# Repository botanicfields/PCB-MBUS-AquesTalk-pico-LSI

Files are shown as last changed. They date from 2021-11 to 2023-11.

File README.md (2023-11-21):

# PCB-MBUS-AquesTalk-pico-LSI
# M5Stack用 AquesTalk pico LSIモジュール基板
M-BUS Module of AquesTalk pico LSI for M5Stack

# 1. 概要
　市販の音声合成専用LSI「AquesTalk pico LSI」（別売）をM-BUSモジュールとしてM5Stackに取り付けるための半完成基板です。  
　AquesTalk pico LSIの詳細は、データシートを参照ください。  
[Data Sheet: 音声合成 LSI 「AquesTalk pico LSI」ATP3011](https://www.a-quest.com/archive/manual/atp3011_datasheet.pdf)  
[Data Sheet: 音声合成 LSI 「AquesTalk pico LSI」ATP3012](https://www.a-quest.com/archive/manual/atp3012_datasheet.pdf)

### 基板V04の変更点
　2022年10月末から基板V04を提供しています。詳細は、スピーカーの接続の項を参照ください。

- ハンダジャンパJP8, JP9を追加しました。
- ランドJ5を追加しました。

### 委託販売
（スイッチサイエンス扱い）[M5Stack用 AquesTalk pico LSI モジュール基板](https://www.switch-science.com/collections/marketplace/products/7624)

### 動作例
（YouTube）["AquesTalk pico LSI" speaks date and time](https://youtu.be/DpDmjqU7RUM)  
（YouTube）[M-Bus Module of AquesTalk pico LSI drives the built-in speaker of M5Stack](https://youtu.be/npRQEOJegkY)  
（YouTube）[M-Bus Module of AquesTalk pico LSI for M5Stack](https://youtu.be/YfKwWRxrInM)  
（YouTube）[M-Bus Module of AquesTalk pico LSI for M5Stack on Core2](https://youtu.be/zXvg78xzJ5E)

### 組み立て例
　組み立てにはハンダ付けが必要です。

左側: ATP3011を搭載、音声アナログ信号をGPIO35に入力するためJP5をショート  
右側: ATP3012を搭載、音声アナログ信号をGPIO35に入力するためJP6をショート  
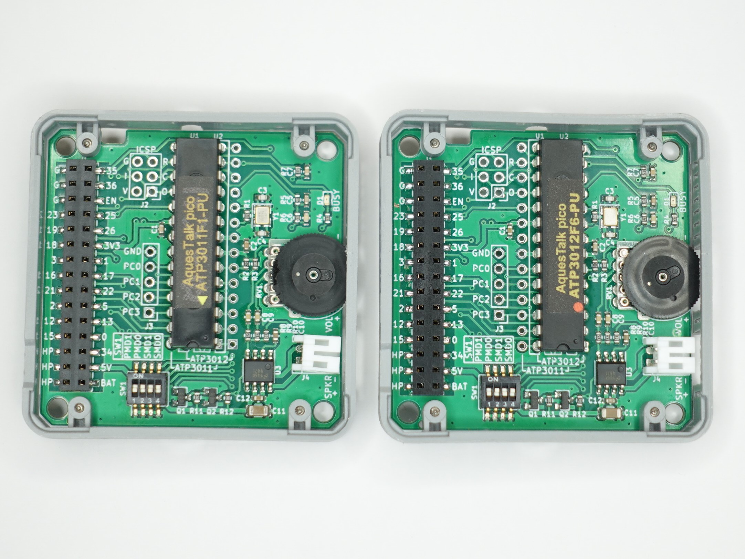
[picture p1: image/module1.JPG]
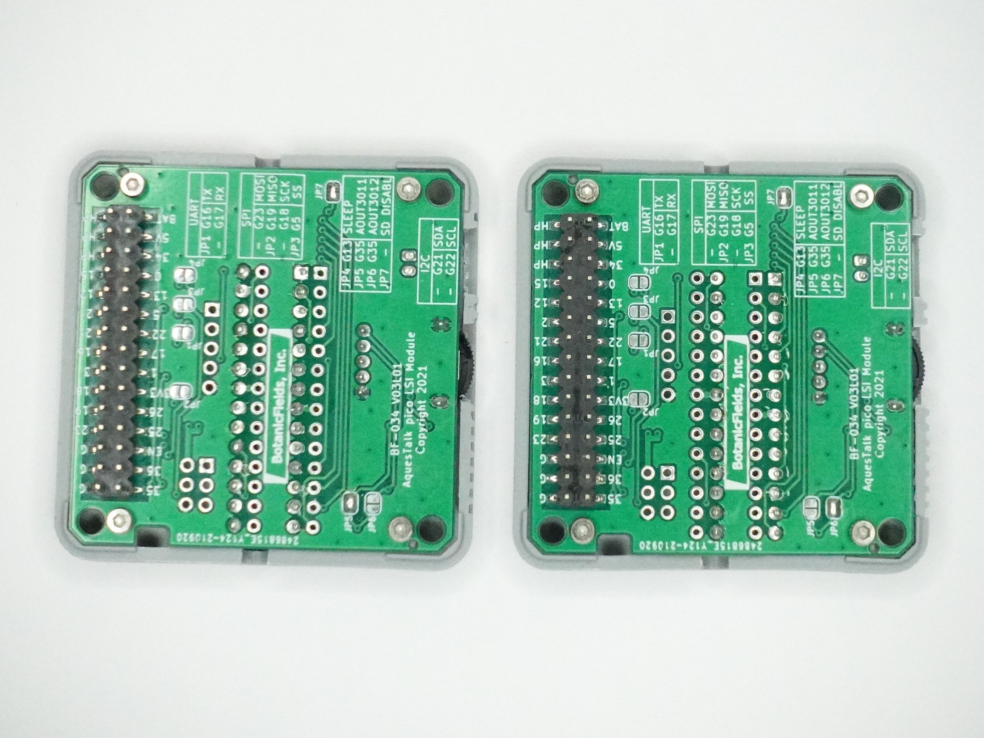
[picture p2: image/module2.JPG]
   
写真右: M5Stack 取り付け例、J4に外部スピーカを接続  
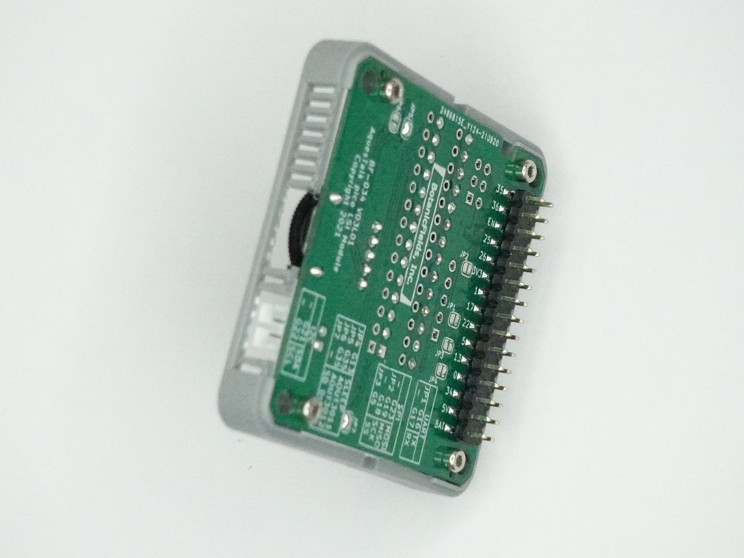
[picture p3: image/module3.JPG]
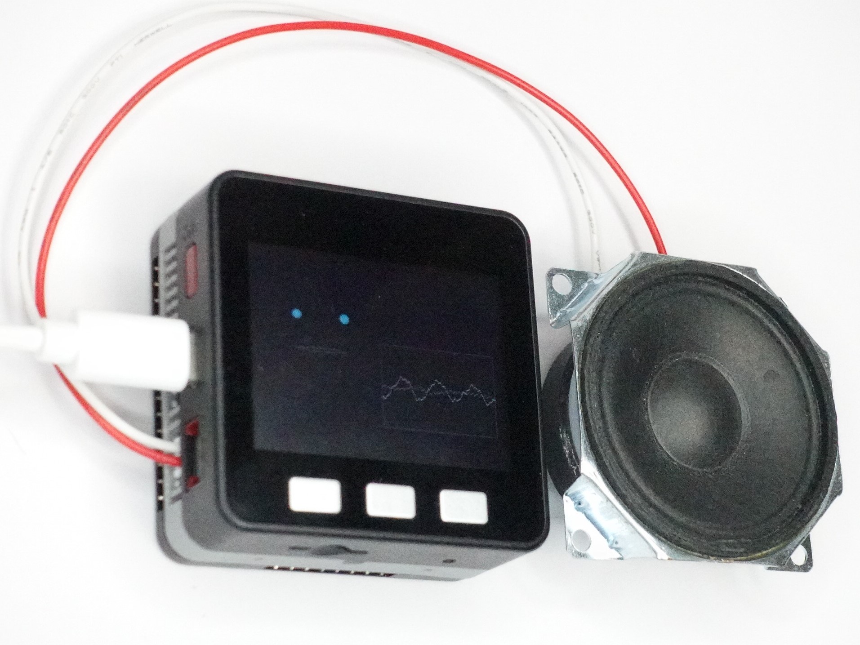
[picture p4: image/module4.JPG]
 

## 1.1 特徴
- AquesTalk pico LSI（28ピンDIPタイプ）1個を搭載できます。
- ATP3011, ATP3012の両方に対応しています。
- パワーアンプ（LM4871）を内蔵し、スピーカーを直接駆動できます。
- AquestTalk pico LSIを3.3Vで動作させ、M-BUSに直結できます。
- プロトモジュールのモールド（別売）を流用し、M5Stackに取り付けできます。
- スピーカー以外のケーブル接続が不要です。
- DIP スイッチで動作モード・通信モードを設定できます。
- インタフェースをI2C, UART, SPIから選べます。
- AquesTalk pico LSIの音声出力をM-BUSから取り込めます。
- M5StackのリセットでAquesTalk pico LSIをリセットします。
- スタンドアロンモードのためのランドがあります。

DIP: Dual In-line Package  
I2C: Inte-Integrated Circuit  
UART: Universal Asynchronous Receiver Transmitter  
SPI: Serial Peripheral Interface

## 1.2 商品内容
- M-BUS モジュール基板（半完成品）1枚  
- スピーカーケーブル 1組（2ピンPH相当コネクタ付き、20cm片端ストリップ済）  
（秋月電子通商扱い）[コネクタ付コード２Ｐ（Ａ）（赤白）DG01032-0045-01(C5679)](https://akizukidenshi.com/catalog/g/gC-05679/)
- 説明書 1部

※ AquesTalk pico LSIは付属しません。  
※ プロトモジュールのモールドは付属しません。  
※ スピーカーは付属しません。

### 商品写真
写真左: 内容物(基板V4)、写真右: 基板V4裏面  
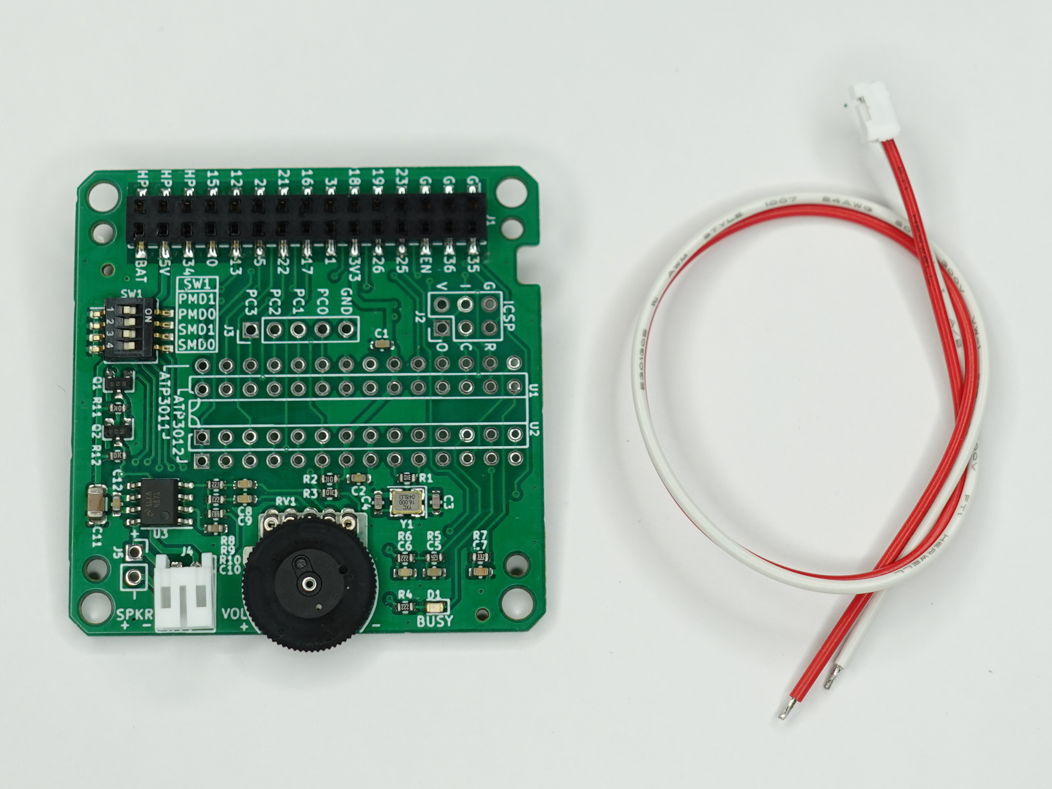
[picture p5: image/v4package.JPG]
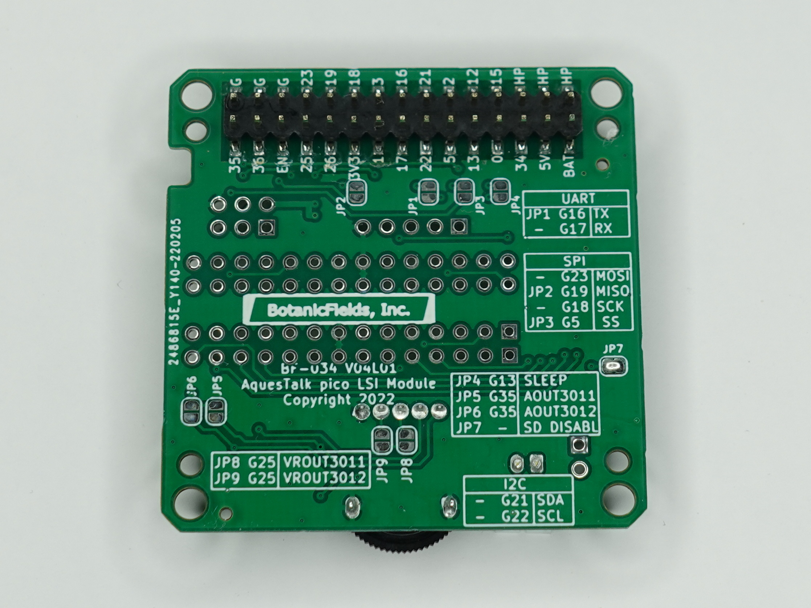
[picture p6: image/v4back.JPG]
 

## 1.3 別途必要なもの
- AquesTalk pico LSI（秋月電子通商扱い）  
[音声合成ＬＳＩ　ＡＴＰ３０１１Ｆ１－ＰＵ（ゆっくりな女性の音声）
ATP3011F1-PU](https://akizukidenshi.com/catalog/g/gI-06220/)  
[音声合成ＬＳＩ　ＡＴＰ３０１１Ｆ４－ＰＵ（かわいい女性の音声）
ATP3011F4-PU](https://akizukidenshi.com/catalog/g/gI-05665/)  
[音声合成ＬＳＩ　ＡＴＰ３０１１Ｍ６－ＰＵ（男性の音声）
ATP3011M6-PU](https://akizukidenshi.com/catalog/g/gI-06225/)  
[音声合成ＬＳＩ　ＡＴＰ３０１２Ｆ６－ＰＵ（女性の音声明瞭版）
ATP3012F6-PU](https://akizukidenshi.com/catalog/g/gI-09973/)  
[音声合成ＬＳＩ　ＡＴＰ３０１２Ｒ５－ＰＵ（小型ロボットの音声）
ATP3012R5-PU](https://akizukidenshi.com/catalog/g/gI-11517/)
- プロトモジュール  
（スイッチサイエンス扱い）[M5Stack用プロトモジュール](https://www.switch-science.com/catalog/3650/)
- スピーカー  
4～8Ω程度、1W以上が望ましいです。
- 工具  
ハンダ、ハンダごて、ニッパー、六角レンチ(1.5mm)、カッター、ピンセットなど
- M5Stack  
サンプルプログラムは、主にM5Stack Core Basicで動作を確認しています。
- Arudino-IDEが動作する環境  

# 2. モジュール基板の組み立て

## 2.1 AquesTalk pico LSI の取り付け
　別売のAquestTalk pico LSI（28ピンDIPタイプ）1個を取り付けます。ATP3011とATP3012とでは挿入する穴が異なります。基板上のシルク印刷に従ってピンを挿入しハンダ付けします。モジュール基板裏面から飛び出しているピンを短く切ってください。

左: ATP3011, 右: ATP3012  
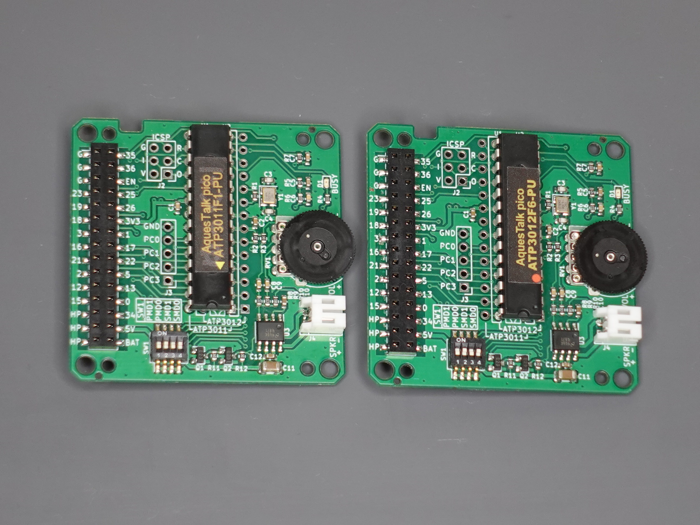
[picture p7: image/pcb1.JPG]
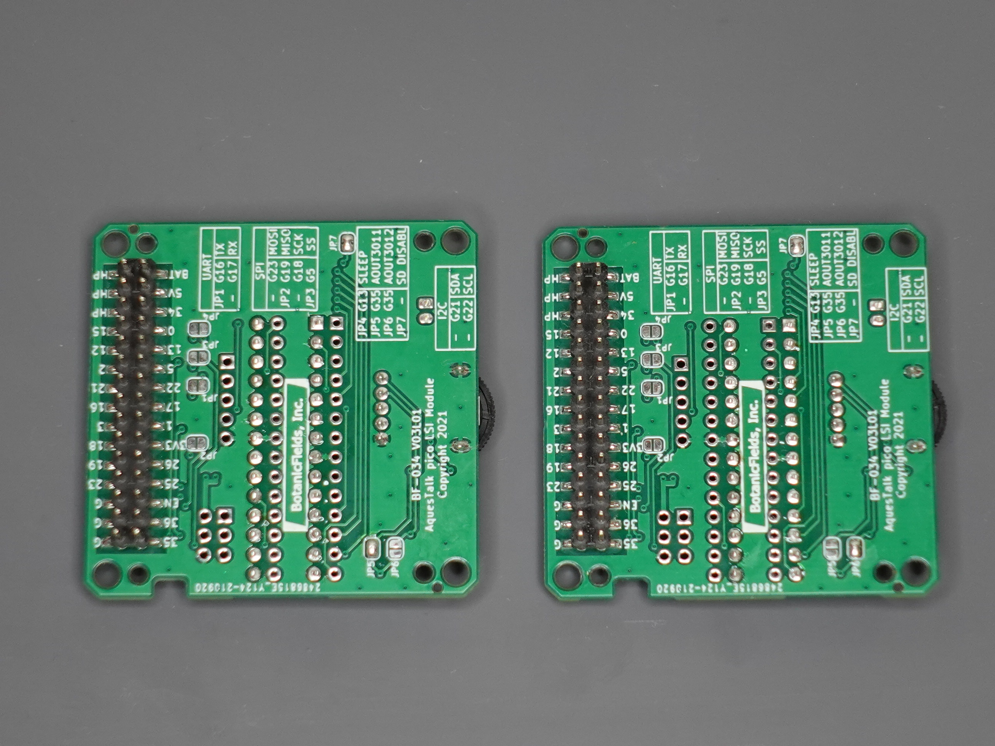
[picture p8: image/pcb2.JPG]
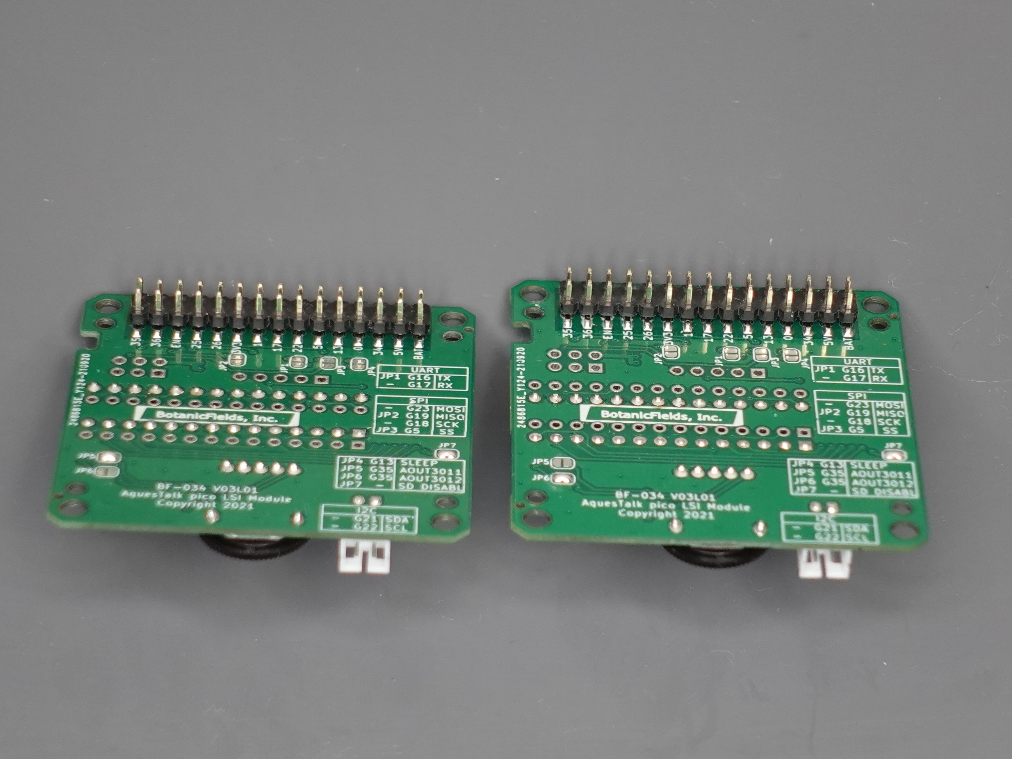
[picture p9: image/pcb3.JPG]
   

### ICソケットは使用できません
　ICソケットを使用すると、プロトモジュールのモールドには収まらなくなります。収まらなくなることを承知の上で1列タイプのICソケットを使用するとATP3011とATP3012を差し換えることができます。モジュール基板裏面からのピンの飛び出しの対処も大変になります。

- ICソケット（秋月電子通商扱い）  
[丸ピンＩＣ用ソケット　（シングル１４Ｐ）　１×１４　
6604S-14](https://akizukidenshi.com/catalog/g/gP-03470/)  
[丸ピンＩＣ用ソケット　（シングル１４Ｐ）　１×１４　
JS-11791SFTD-14](https://akizukidenshi.com/catalog/g/gP-11451/)  ※在庫限り  

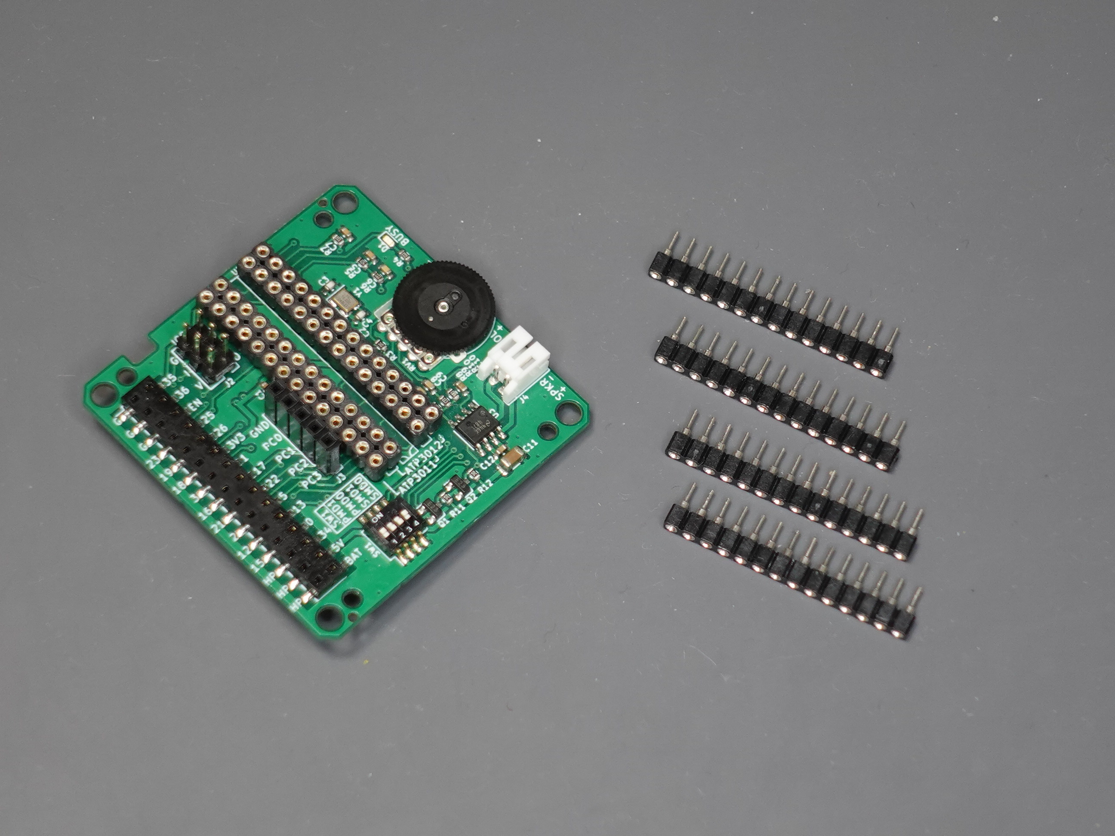
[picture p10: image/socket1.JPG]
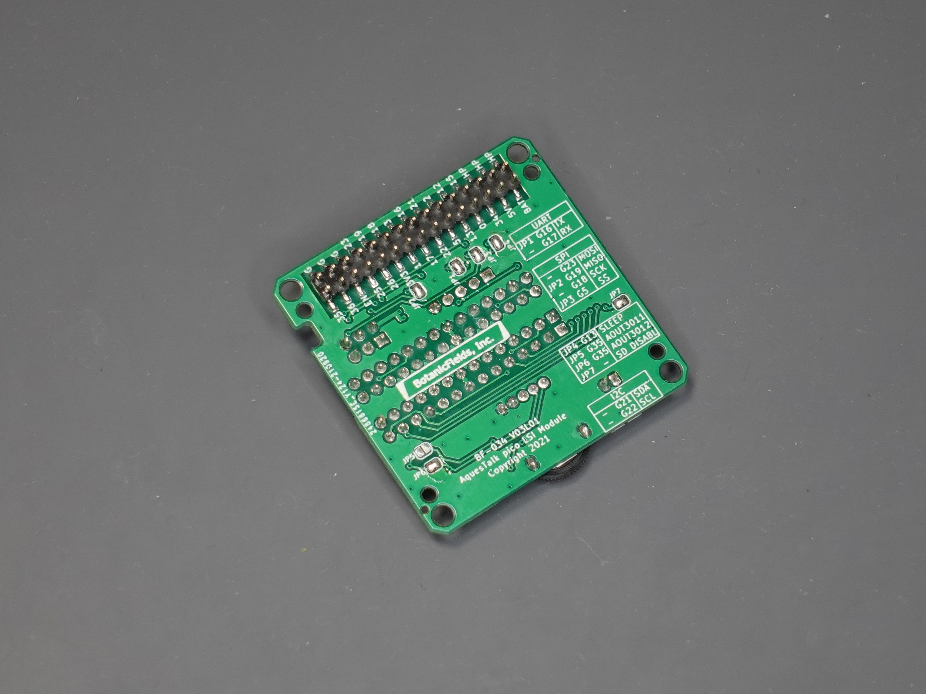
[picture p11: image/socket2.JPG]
 

## 2.2 モールドの取り付け
　プロトモジュールのモールドおよびネジ4本（別売）を流用して、M5StackのM-BUSモジュールに仕立てることができます。モールドを基板に取り付ける前に、ボリュームやスピーカー出力コネクタの部分をモールドから切り取ります。
### モールドの入手先（スイッチサイエンス扱い）

- [M5Stackプロトモジュール用プラスチックフレーム（2個入）](https://www.switch-science.com/collections/m5stack/products/8450)
- [M5Stack用プロトモジュール [M001]](https://www.switch-science.com/collections/m5stack/products/3650)

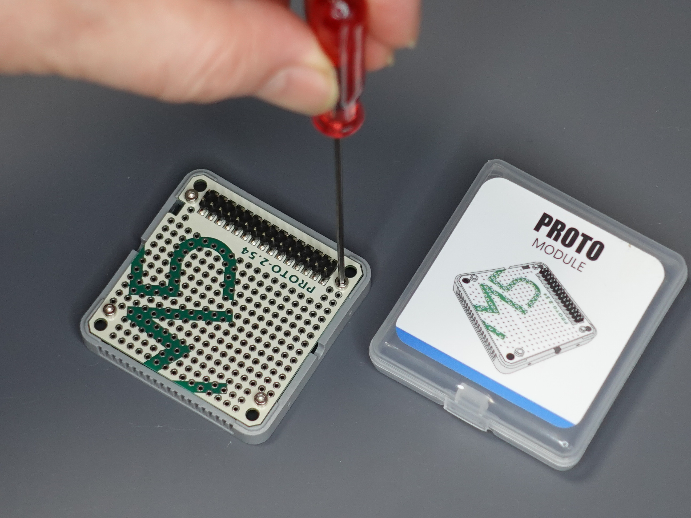
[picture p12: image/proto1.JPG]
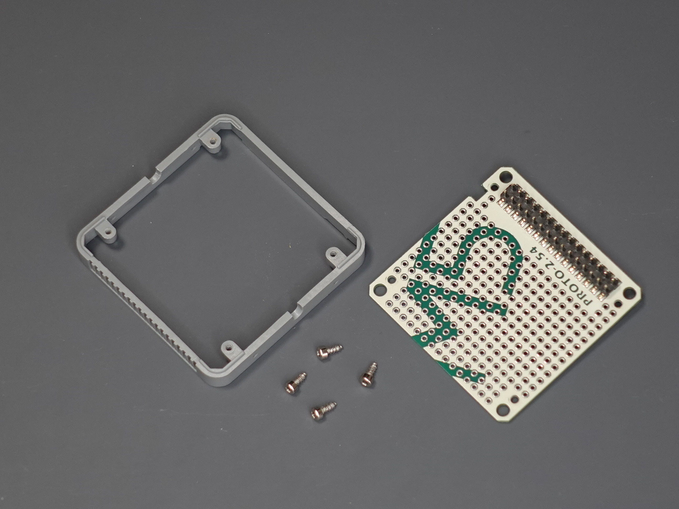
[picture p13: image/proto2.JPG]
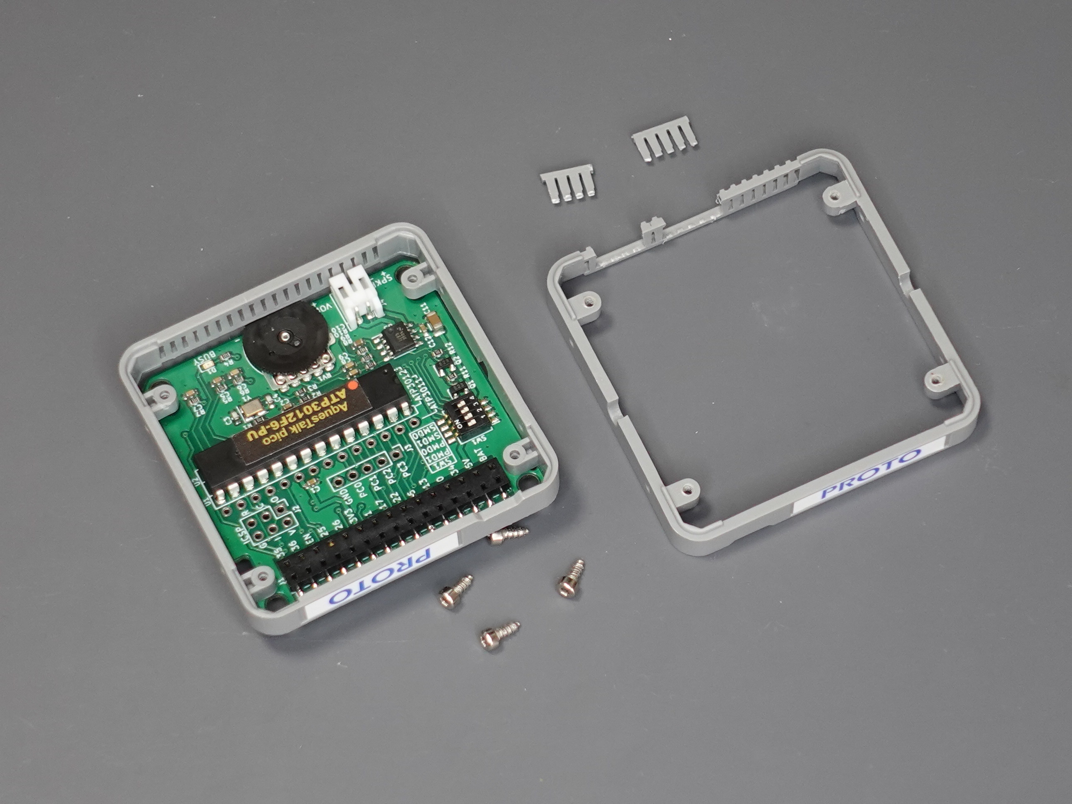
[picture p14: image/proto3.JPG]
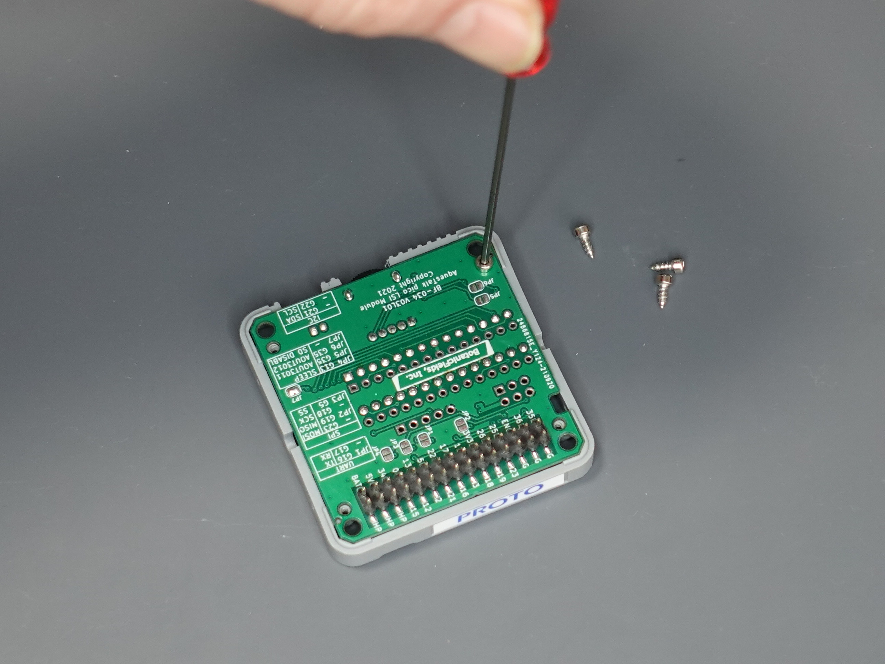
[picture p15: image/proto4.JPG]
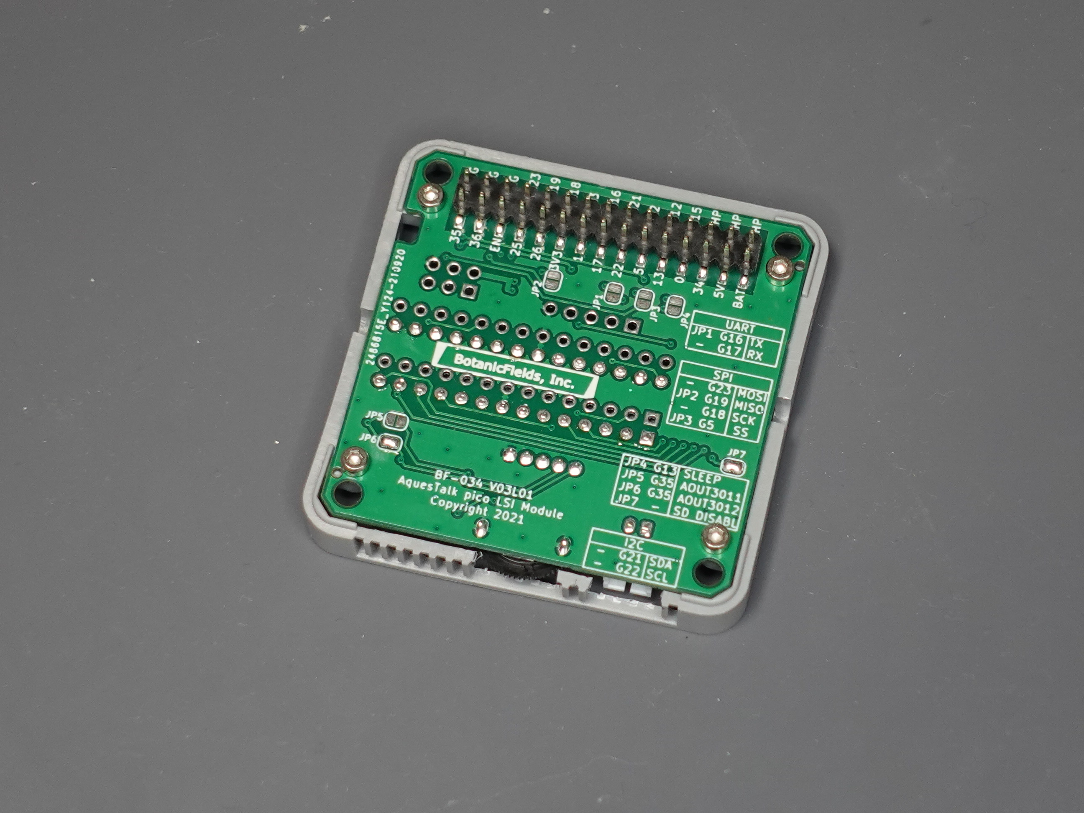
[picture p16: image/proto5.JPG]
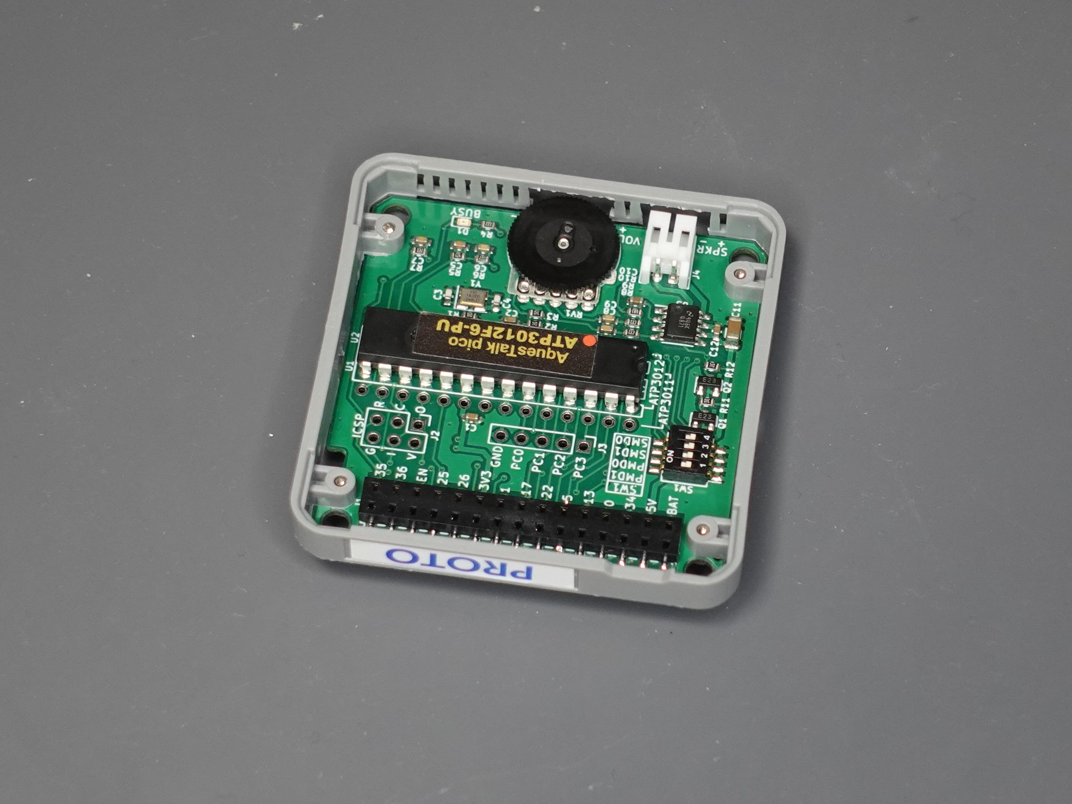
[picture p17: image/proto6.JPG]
     

## 2.3 スピーカーの接続

- 付属のケーブルでJ4とスピーカー（付属せず）を接続します。GNDには接続しないでください。
- （基板V4）J5にスピーカーを接続することができます。GNDには接続しないでください。
- （基板V4）M5Stack(Core1)の内蔵スピーカーを使用できます。ATP3011の場合はJP8を、ATP3012の場合はJP9をショートしてください。M5Stack本体からGPIO25を使用しないでください。Core2は内蔵スピーカーの回路構成が異なるため、この方法は使えません。  

左側: ATP3011を搭載、GPIO25, 35に接続するためJP8, JP5をショート(基板V4)  
右側: ATP3012を搭載、GPIO35に接続するためJP6をショート、J5にスピーカを接続(基板V4)  

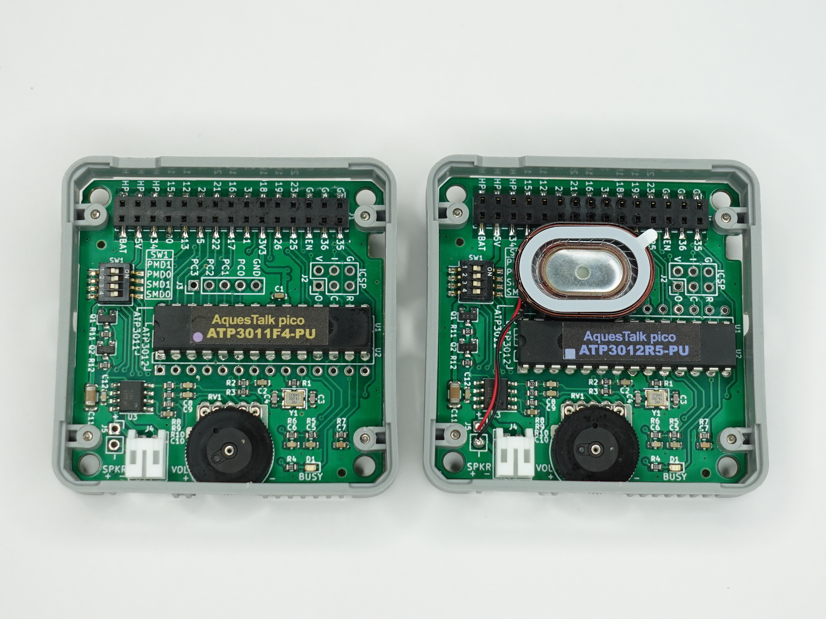
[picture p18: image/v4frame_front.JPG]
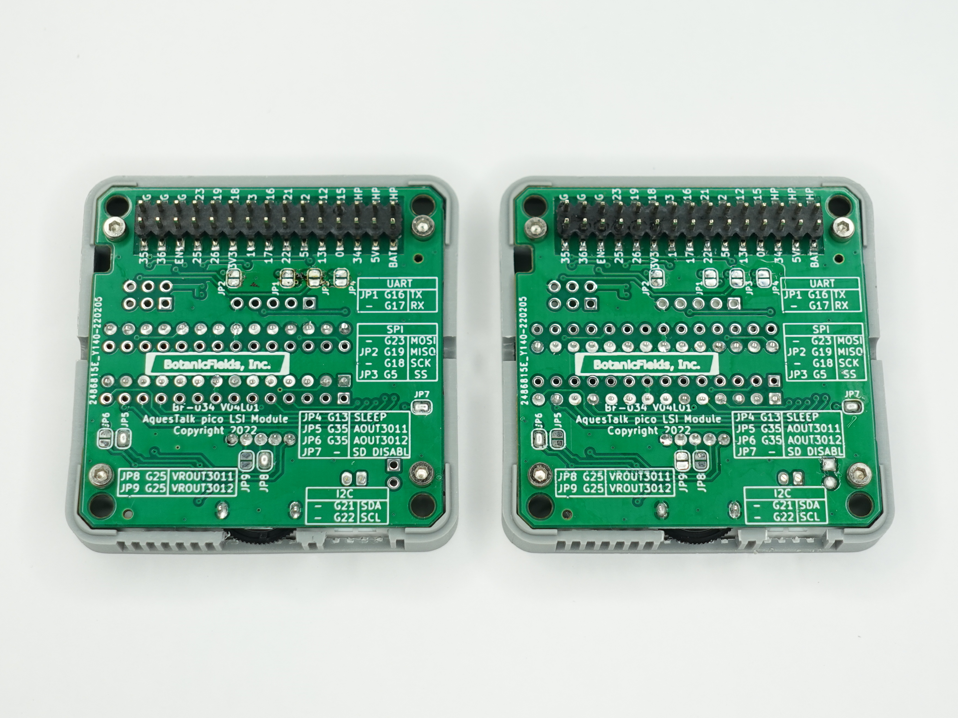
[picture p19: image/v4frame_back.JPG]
   

参考：写真のスピーカーは以下を両面テープで固定しています。ATP3012の場合かろうじて収まります。上に重ねるモジュールやボトムによっては収まりません。  
（秋月電子通商扱い）  
[マイクロスピーカー　赤／黒リード付　８Ω](https://akizukidenshi.com/catalog/g/gP-12494/)  
[マイクロスピーカー　青／白リード付　８Ω](https://akizukidenshi.com/catalog/g/gP-12495/)

### M5Stackの内蔵スピーカーについて
　M-BUSのGPIO25は、M5Stack内部のオーディオアンプを通して内蔵スピーカーに繋がっています。AquesTalk pico LSIからの音声出力をGPIO25に入力すれば、内蔵スピーカーから音声を出すことができます。ボリューム(VR)の出力を用いることで音量調節が可能です。以下の写真は、ATP3011を載せたモジュールにおいてGPIO25とボリューム出力を導線で接続した例です。ATP3012の場合は、ボリューム出力は1つ左側のピンです。基板V4のJP8, JP9はこれらの導線を埋め込んだものです。M5Stack自身がGPIO25を使わないことが前提です。Core2は内蔵スピーカーの回路構成が異なるため、この方法は使えません。

VR: Variable Resistor

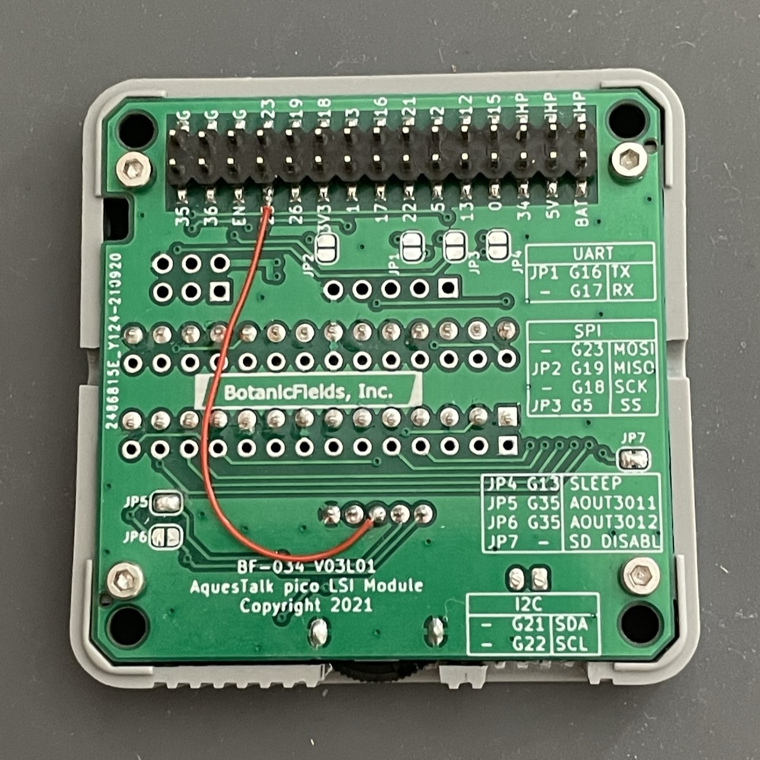
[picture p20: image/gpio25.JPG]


## 2.4 その他の端子
- J2は、ICSPです。コネクタ等は実装していません。使用にはピンヘッダをハンダ付けするなどの処置が必要です。ICSPのVCCはAquesTalk pico LSIの電源端子に繋がっているほか、M-BUSの3.3Vにも繋がっています。ICSPは、モジュール基板をM5Stackから切り離し、単体にして接続してください。  
ICSP: In Circuit Serial Programming  

- J3は、スタンドアロンモードで使用するPC0-3およびGNDの端子です。コネクタ等は実装していません。使用には信号ケーブルを直接ハンダ付けするなどの処置が必要です。

### スタンドアロン接続例
　M5Stack用 AquesTalk pico LSIモジュールをM-Busエクステンションに載せ、ダイオードマトリクススイッチ16基板を接続しています。M5Stackの電源とリセットを使用しています。  
（スイッチサイエンス扱い）[M-Busエクステンション基板キット](https://www.switch-science.com/catalog/7371/)  
（スイッチサイエンス扱い）[ダイオードマトリクススイッチ16基板](https://www.switch-science.com/catalog/7626/)  
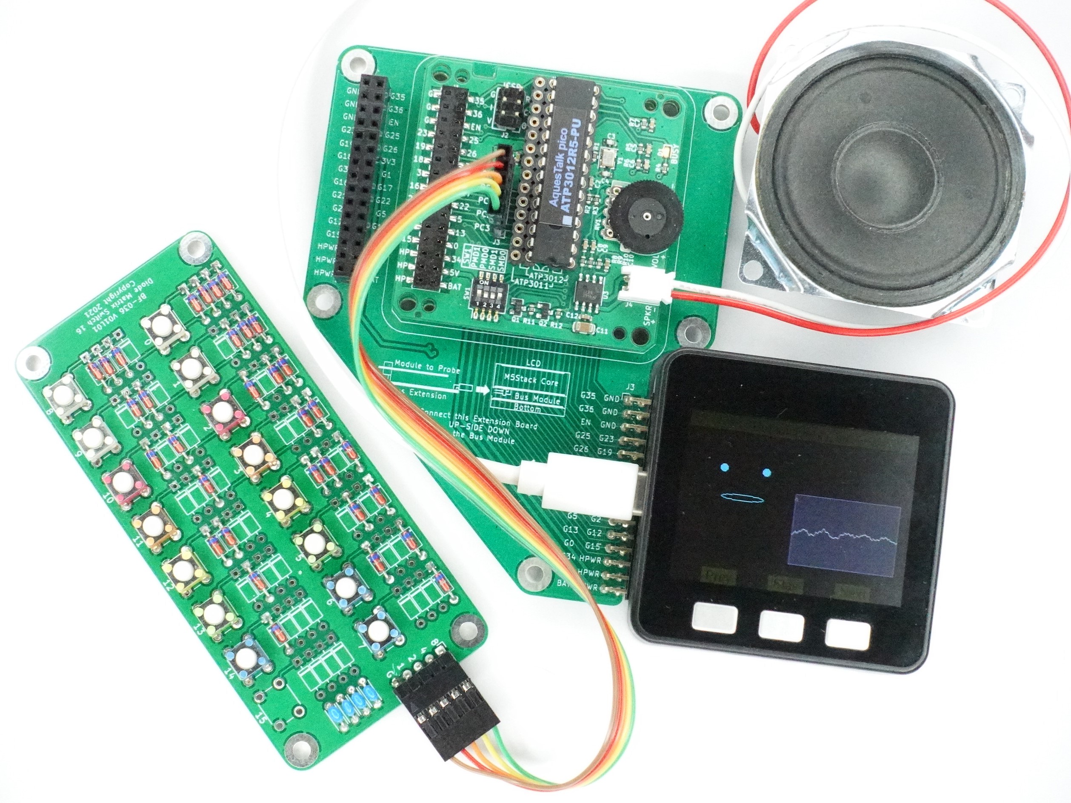
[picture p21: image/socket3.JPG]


# 3. モジュールの設定

## 3.1 DIPスイッチによる動作モード・通信モードの設定
　動作モードおよび使用するインタフェース（通信モード）に合わせて、モジュール基板上のDIPスイッチを設定します。設定にはピンセットなどが必要です。おすすめはI2C接続です。出荷時の設定は、セーフモード・I2C接続です。DIPスイッチの設定はリセット時に反映されます。AquesTalk pico LSIのリセットはM5Stackのリセットに繋がっています。

| 1 | 2 | 3 | 4 |動作モード|通信モード|備考|
|:-:|:-:|:-:|:-:|:-:|:-:|:- |
|OFF|OFF|OFF|ON | コマンド入力モード |I2C |I2CアドレスはEEPROMに設定した値（初期値0x2E）|
|OFF|ON |OFF|ON | セーフモード |I2C |I2Cアドレスは強制的に0x2E|
|OFF|OFF|OFF|OFF| コマンド入力モード |UART|設定されたスピードで動作 (*1) |
|OFF|ON |OFF|OFF| セーフモード |UART|強制的に9600bpsで動作|
|OFF| - |ON |OFF| - | SPI mode 3 | - |
|OFF| - |ON |ON | - | SPI mode 0 |サンプルプログラムはSPI mode 0で動作|
|ON |OFF| - | - | スタンドアロンモード | - |PC0-3の信号入力によりプリセットメッセージを選択して再生|
|ON |ON | - | - | デモモード | - |プリセットメッセージを順番に自動再生|

※ 1, 2, 3, 4は、DIPスイッチの番号。DIPスイッチはON=GNDのため、ON=0, OFF=1です。  
(*1) ATP3011の場合、SLEEP解除後の'?'送信で自動設定します。ATP3012の場合EEPROMに設定します。

## 3.2 ハンダジャンパによる信号の接続
　モジュール基板裏面のジャンパJP1-JP9をハンダで短絡（クローズ）することにより、GPIOとAquesTalk pico LSIの信号ピンを接続できます。

|ジャンパ|GPIO(Core1)|GPIO(Core2)|AquesTalk pico LSI|出荷時|
|:-:|:-:|:-:|:-|:-:|
|JP1|16|13|UART-TX|オープン|
|JP2|19|38|SPI-MISO|オープン|
|JP3|5|33|SPI-SS|オープン|
|JP4|13|19|SLEEP|オープン|
|JP5|35|35|Analog Out of ATP3011|オープン|
|JP6|35|35|Analog Out of ATP3012|オープン|
|JP7|GND|GND|Shut Down of Power Amplifier|クローズ|
|JP8|25|25|Analog VR Out of ATP3011|オープン|
|JP9|25|25|Analog VR Out of ATP3012|オープン|

### JP1, JP2, JP3: インタフェース信号
　使用するインタフェースに合わせてJP1, JP2, JP3をハンダで短絡（クローズ）します。I2Cの場合はJP1, JP2, JP3を全てオープンのままで使用できます。他の用途に影響がなければJP1, JP2, JP3を短絡（クローズ）することで全てのインタフェースを使用可能です。出荷時はオープンです。

|インタフェース|JP1|JP2|JP3|AquestTalk pico LSIピン=GPIO(Core1)|AquestTalk pico LSIピン=GPIO(Core1)|
|:-:|:-:|:-:|:-:|:- |:- |
|I2C| - | - | - |SDA=21, SCL=22|SDA=21, SCL=22|
|UART|クローズ| - | - |TX=16, RX=17|TX=13, RX=14|
|SPI| - |クローズ|クローズ|SCK=18, MISO=19, MOSI=23, SS = 5|SCK=18, MISO=38, MOSI=23, SS = 33|

SDA: Serial DAta  
SCL: Serial CLock  
RX: Receive  
TX: Transmit  
MISO: Master In Slave Out  
MOSI: Master Out Slave In  
SCK: Serial ClocK  
SS: Slave Select

### JP4: SLEEP 信号
　AquesTalk pico LSIのSLEEPピンをGPIO13(Core2ではGPIO19)に接続できます。SLEEP=LowでAquesTalk pico LSIがスリープ状態になります。ATP3011のUART接続において9600bpsより速い速度が必要な場合、「セーフモード」ではなく「コマンド入力モード」に設定し、速度設定のためにSLEEPを使用します。出荷時はオープンです。

### JP5, JP6: 音声信号の取り込み
　AquesTalk pico LSIの音声出力をGPIO35経由でM5Stackに取り込むことができます。ATP3011の場合はJP5を、ATP3012の場合はJP6をハンダで短絡（クローズ）します。出荷時はオープンです。

### JP7: パワーアンプのシャットダウン
　JP7がクローズ（短絡）の場合、パワーアンプのシャットダウン（SD: Shut Down）信号をGNDに接続しパワーアンプを常に動作状態とします。JP7のハンダを取り除く（オープン）にすると、AquesTalk pico LSIのPLAY信号（負極性）がシャットダウン信号となり、パワーアンプの消費電力を減らすことができます。この設定では音声再生の前後でノイズが発生します。出荷時はクローズ（短絡）です。

### JP8, JP9（基板V4）: M5Stack(Core1)の内蔵スピーカーへの接続
　AquesTalk pico LSIの音声出力をボリューム調節後にGPIO25経由でM5Stack内蔵アンプ・スピーカーに接続することができます。ATP3011の場合はJP8を、ATP3012の場合はJP9をハンダで短絡（クローズ）します。出荷時はオープンです。

# 4. サンプルプログラム
　AquesTalk pico LSIをM5Stackに接続し、I2C(Wire), UART(Serial), SPIで動作させるプログラムです。デモの内容は同じです。Arduino-IDE環境で使用します。モジュール基板の設定を予め使用するインタフェースに合わせておく必要があります。

### BF-034_Wireフォルダ
　AqeusTalk pico LSIをI2Cで動作させるサンプルプログラムです。

### BF-034_Serialフォルダ
　AqeusTalk pico LSIをUARTで動作させるサンプルプログラムです。

### BF-034_Spiフォルダ
　AqeusTalk pico LSIをSPIで動作させるサンプルプログラムです。

### BF-034_Core2_Wireフォルダ
　Core2にモジュールを装着して、AqeusTalk pico LSIをI2Cで動作させるサンプルプログラムです。M5Stack Core1との違いは以下です

- includeするヘッダーファイル
- WireのGPIOピン番号、SleepのGPIOピン番号

## 4.1 ボタン操作 .. loop()
　ボタンを押すと、ソースコードのpreset_msgを発声します。初期値はpreset_msg[0]です。

| M5 | ボタン | 停止中 | 発声中 |
|:-:|:-:|:-:|:-:|
|M5Stack| A | 1つ前のpreset_msgを発声 | 発声を中断して1つ前のpreset_msgを発声 |
|M5Stack| B | 現在のpreset_msgを発声 | 発声を中断して停止 |
|M5Stack| C | 1つ後のpreset_msgから連続して発声 | 発声を中断して1つ後のpreset_msgから連続して発生 |

## 4.2 setup()
- SLEEP ピンをHighにする（デフォルト: 実行する）  
　JP4をクローズ（短絡）すると、GPIO13(Core2ではGPIO19)とAquesTalk pico LSIのSLEEPピンとが接続します。SLEEPをHIGHにしてSLEEPでない状態にします。

- UARTスピードを設定（ATP3011が対象。UARTのみ。デフォルト: 実行しない）  
　AquesTalk pico LSI (ATP3011) のUARTスピードを設定します。GPIO13(Core2ではGPIO19)がAquesTalk pico LSIのSLEEPピンと接続している必要があります。

- UARTスピードを書き換え（ATP3012が対象。UARTのみ。デフォルト: 実行しない）  
　AquesTalk pico LSI (ATP3012) のUARTスピードを書き換えます。

- I2Cアドレスを書き換え（I2Cのみ。デフォルト: 実行しない）  
　AquesTalk pico LSIのI2Cアドレスを書き換えます。

- プリセットメッセージを書き込む（デフォルト: 実行しない）  
　AquesTalk pico LSIにプリセットメッセージとして、ソースコード内のpreset_msgデータを書き込みます。時間がかかります。

- EEPROMデータをダンプ（デフォルト: 実行しない）  
　AquesTalk pico LSIのEEPROMデータをシリアルモニタに表示します。時間がかかります。

- AquesTalk pico LSIのバージョンをシリアルモニタに表示

- チャイムJを発声

- チャイムKを発声

# 5. ライブラリ
　AquesTalk pico LSIを使用するためのライブラリです。

## 5.1 BF_AquesTalkPico.h
　I2C, UART, SPI共通の基本クラスです。接続するインタフェースに依ってI2C(Wire), UART(Serial), SPIのいずれかの派生クラスを使用する必要があります。

### (1) virtual int Send(const char* msg) = 0
　AquesTalk pico LSIに文字列msgを送信します。送信の様子をシリアルモニタに出力します。純粋仮想関数として定義し、使用するインタフェースに合わせて派生クラスで実装します。

### (2) virtual size_t Recv(char* res, size_t res_size) = 0
　AquesTalk pico LSIから文字列を受信します。受信完了は、'>'または'*'で判断します。純粋仮想関数として定義し、使用するインタフェースに合わせて派生クラスで実装します。

### (3) virtual bool Busy() = 0
　発声中などAquesTalk pico LSIが処理中の場合trueを応答します。falseの場合発声が終了したと判断できます。純粋仮想関数として定義し、使用するインタフェースに合わせて派生クラスで実装します。I2C, SPIではおのずとポーリングができますが、UARTではSend()による明示的なポーリングが必要です。

### (4) int ShowRes(int res_length_to_show = 1)
　AquesTalk pico LSIからの応答をシリアルモニタに出力します。res_length_to_showに2を渡すと、応答が1文字以下の場合にシリアルモニタへの出力を抑止できます。I2C、SPIのポーリングによる応答が正常（'>', 1文字）の場合のシリアルモニタへの出力を省略できます。

### (5) int DumpEeprom()
　AquesTalk pico LSIのEEPROM (アドレス0x000-0x3FF) の値をシリアルモニタに出力します。

### (6) int WriteEeprom(int address, int data)
　AquesTalk pico LSIのEEPROMにデータを書き込みます。

### (7) int WritePresetMsg(const char* msg[], int num_of_msg)
　AquesTalk pico LSIのEEPROMにプリセットメッセージを書き込みます。書き込みの様子をシリアルモニタに出力します。

### (8)  int WriteSpeed(int speed)
　発話速度をEEPROMに設定します。50～300を設定できます。デフォルトは100です。

### (9)  int WritePause(int pause)
　文末ポーズの長さをEEPROMに設定します。256～65535を設定できます。65535を設定すると自動になります。デフォルトは65535です。

### (10) int WriteSerialSpeed(int serial_speed)
　AquesTalk pico LSI (ATP3012) のシリアル通信速度を書き換えます。デフォルトは9600です。

### (11) int WriteI2cAddress(int i2c_address)
　AquesTalk pico LSIのI2Cアドレスを書き換えます。デフォルトは0x2Eです。

## 5.2 BF_AquesTalkPicoWire.h
　AquesTalk pico LSIとI2Cでインタフェースする派生クラスです。

### int Begin(TwoWire &wire, int i2c_address = 0x2e);
　AquesTalk pico LSIを接続するI2CとI2Cアドレスを指定します。

## 5.3 BF_AquesTalkPicoSerial.h
　AquesTalk pico LSIとUARTでインタフェースする派生クラスです。

### int Begin(Stream &stream);
　AquesTalk pico LSIを接続するUARTを指定します。

## 5.4 BF_AquesTalkPicoSpi.h
　AquesTalk pico LSIとSPIでインタフェースする派生クラスです。

### int Begin(SPIClass &spi, int ss);
　AquesTalk pico LSIを接続するSPIとSSとして使用するGPIOを指定します。

# 6. BF-034_Clockフォルダ
　M5StackのLCDに日付・時刻を表示する置時計のデモです。

- リセット後はsetupの状況を表示します。setupが完了しボタンCを押すと時計表示になります。
- ボタンBで日付を音声で読み上げます。ボタンCで時刻を音声で読み上げます。

### ご注意
　WiFi動作中に発声すると電圧低下を検出してリブートすることがあります。

### 参考情報

- Qiita: [ESP32のWiFiおよびtzapu/WiFiManagerにおいて回復処理を試行錯誤した](https://qiita.com/BotanicFields/items/8a73101a8bfe51e57f67)
- Qiita: [ESP32 において NTP の時刻同期を捕まえて RTC を更新する](https://qiita.com/BotanicFields/items/f1e28af5a63e4ccf7023)
- Qiita: [M5Atom, M5Stack Core 用の I2C リアルタイムクロック基板を作って動かす](https://qiita.com/BotanicFields/items/dc35e12423be8f6e9b4e)

# 7. 参考
- Qiita: [AquesTalk pico LSI を M5Stack の I2C, UART, SPI で動かす](https://qiita.com/BotanicFields/items/fff644f408c291e5a5f0)

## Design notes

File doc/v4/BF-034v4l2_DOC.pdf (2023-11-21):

BF-034 V04L02

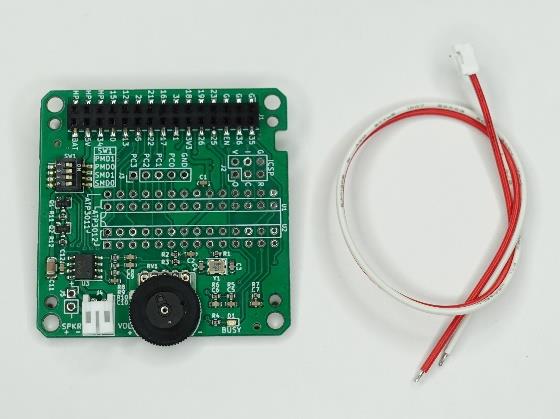
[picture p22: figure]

1 | Copyright 2022 BotanicFields, Inc.

## M5Stack 用 AquesTalk pico LSI モジュール基板

市販の音声合成専用 LSI「AquesTalk pico LSI」（別売）を M-BUS モ ジュールとして M5Stack に取り付けるための半完成基板です。 詳細は、以下を参照ください。
GitHub「PCB-MBUS-AquesTalk-pico-LSI」 https://github.com/botanicfields/PCB-MBUS-AquesTalk-pico-LSI Qiita「AquesTalk pico LSI を M5Stack の I2C, UART, SPI で動かす」 https://qiita.com/BotanicFields/items/fff644f408c291e5a5f0

AquesTalk pico LSI の詳細は、データシートを参照ください。 ATP3011: https://www.a-quest.com/archive/manual/atp3011_datasheet.pdf ATP3012: https://www.a-quest.com/archive/manual/atp3012_datasheet.pdf

1. 特徴

① AquesTalk pico LSI（28 ピン DIP タイプ）1 個を搭載できます。
② ATP3011, ATP3012 の両方に対応しています。
③ パワーアンプ（LM4871）を内蔵し、スピーカーを直接駆動できます。
④ AquesTalk pico LSI を 3.3V で動作させ、M-BUS に直結できます。
⑤ プロトモジュール（別売）のモールドを流用し、M5Stack に取り付けできます。 ⑥ スピーカー以外のケーブル接続が不要です。
⑦ DIP スイッチで動作モード・通信モードを設定できます。
⑧ インタフェースを I2C, UART, SPI から選べます。
⑨ AquesTalk pico LSI の音声出力を M-BUS から取り込めます。 ⑩ M5Stack のリセットで AquesTalk pico LSI をリセットします。 ⑪ スタンドアロンモードのためのランドがあります。
2. 商品内容

① M-BUS モジュール基板（半完成品）1 枚 (V04)
② スピーカーケーブル 1 組（2 ピン PH 相当コネクタ付き、20cm 片端ストリップ済） ③ 説明書（本書）

※基板 V04L01 と V04L02 は、製作上の都合による区別であり、機能・レイアウト共に全く同じです。

3. 別途必要なもの

① AquesTalk pico LSI（秋月電子通商扱い）音声合成ＬＳＩ ＡＴＰ３０１１Ｆ１－ＰＵ（ゆっくりな女性の音声）https://akizukidenshi.com/catalog/g/gI-06220/ＡＴＰ３０１１Ｆ４－ＰＵ（かわいい女性の音声） https://akizukidenshi.com/catalog/g/gI-05665/
ＡＴＰ３０１１Ｍ６－ＰＵ（男性の音声） | https://akizukidenshi.com/catalog/g/gI-06225/
ＡＴＰ３０１２Ｆ６－ＰＵ（女性の音声明瞭版） | https://akizukidenshi.com/catalog/g/gI-09973/
ＡＴＰ３０１２Ｒ５－ＰＵ（小型ロボットの音声） https://akizukidenshi.com/catalog/g/gI-11517/ ② M5Stack 用プロトモジュール（スイッチチサイエンス扱い） https://www.switch-science.com/catalog/3650/
③ スピーカー: 4～8Ω 程度、1W 以上が望ましいです。
④ 工具類: ハンダ、ハンダごて、ニッパー、六角レンチ(1.5mm)、カッター、ピンセットなど ⑤ M5Stack: サンプルプログラムは、M5Stack Core Basic で動作確認しています。
⑥ Arduino-IDE が動作する環境
4. モジュール基板の組み立て

① AquesTalk pico LSI の取り付け
AquesTalk pico LSI（28 ピン DIP パッケージ）を 1 個搭載できます。ATP3011 と ATP3012 とでは 取り付け穴が異なります。基板上のシルク印刷に従ってピンを差し込み、ハンダ付けします。ハンダ付 け後、基板裏面から飛び出しているピンを短く切ってください。IC ソケットは使用できません。プロト モジュールのモールドに収まらなくなります。

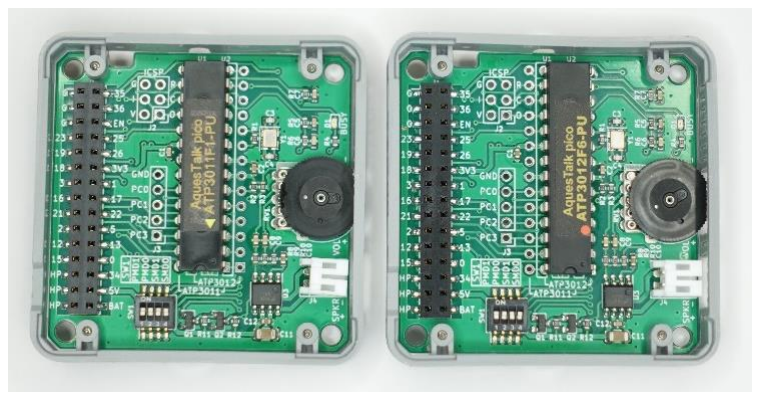
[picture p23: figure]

② モールドの取り付け
プロトモジュール（別売）のモールドおよびネジ 4
本を流用して、M5Stack の M-BUS モジュールに仕立 てることができます。モールドを基板に取り付ける前
に、ボリュームやスピーカー出力コネクタの部分をモ
ールドから切り取ります。

③ スピーカーの接続：以下から選択ください。
(1) 付属のケーブルで J4 とスピーカー（付属せず）を接続します。GND には接続しないでください。
(2) J5 にスピーカーを接続することができます。GND には接続しないでください。
(3) M5Stack(Core1)の内蔵スピーカーを使用できます。ATP3011 の場合は JP8 を、ATP3012 の場 合は JP9 をショートしてください。M5Stack 本体から GPIO25 を使用しないでください。Core2 は内蔵スピーカーの回路構成が異なるため、この方法は使えません。

左: ATP3011 右:ATP3012

5. モジュールの設定

① DIP スイッチ
動作モードおよび使用するインタフェース（通信モード）に合わせて、モジュール基板上の DIP スイ ッチを設定します。設定にはピンセットなどが必要です。おすすめは I2C 接続です。出荷時の設定は、 セーフモード、I2C 接続です。

(*1) ATP3011 の場合 SLEEP 解除後の'?'送信で自動設定。ATP3012 の場合 EEPROM に設定

② ハンダジャンパ
モジュール基板裏面のジャンパ JP1-JP9 をハンダで短絡（クローズ）することにより、GPIO と AquesTalk pico LSI の信号ピンを接続できます。
(1) JP1, JP2, JP3
使用するインタフェースに合わせて JP1, JP2, JP3 をハンダで短絡（クローズ）します。I2C の場合 は JP1, JP2, JP3 を全てオープンのままで使用できます。他の用途に影響がなければ JP1, JP2, JP3 を 短絡（クローズ）することで全てのインタフェースを使用可能です。

DIP スイッチ

1 | 2 | 3 | 4 | 動作モード | 通信モード | 備考
OFF | OFF | OFF | ON | コマンド入力モード | I2C | I2C アドレスは EEPROM に設定した値 （初期値 0x2E）
OFF | ON | OFF | ON | セーフモード | I2C | I2C アドレスは強制的に 0x2E
OFF | OFF | OFF | OFF | コマンド入力モード | UART | 設定されたスピードで動作 (*1)
OFF | ON | OFF | OFF | セーフモード | UART | 強制的に 9600bps で動作
OFF | - | ON | OFF | - | SPI mode 3 | -
OFF | - | ON | ON | - | SPI mode 0 | サンプルプログラムは SPI mode 0 で動作
ON | OFF | - | - | スタンドアロンモード | - | PC0-3 の信号入力によりプリセットメッ セージを選択して再生
ON | ON | - | - | デモモード | - | プリセットメッセージを順番に自動再生
ジャンパ | GPIO(Core1) | GPIO(Core2) | AquesTalk pico LSI | 出荷時設定
JP1 | 16 | 13 | UART-TX | オープン
JP2 | 19 | 38 | SPI-MISO | オープン
JP3 | 5 | 33 | SPI-SS | オープン
JP4 | 13 | 19 | SLEEP | オープン
JP5 | 35 | 35 | Analog Out of ATP3011 | オープン
JP6 | 35 | 35 | Analog Out of ATP3012 | オープン
JP7 | GND | GND | Shut Down of Power Amplifier | クローズ
JP8 | 25 | 25 | Analog VR Out of ATP3011 | オープン
JP9 | 25 | 25 | Analog VR Out of ATP3012 | オープン

(2) JP4
AquesTalk pico LSI の SLEEP ピンを GPIO13(Core2 では GPIO19)に接続できます。SLEEP = Low で AquesTalk pico LSI がスリープ状態になります。ATP3011 の UART 接続において 9600bps より 速い速度が必要な場合、「セーフモード」ではなく「コマンド入力モード」とし、速度設定のために SLEEP を使用します。
(3) JP5, JP6
AquesTalk pico LSI の音声出力を GPIO35 から M5Stack に取り込むことができます。ATP3011 の 場合は JP5 を、ATP3012 の場合は JP6 をハンダで短絡（クローズ）します。
(4) JP7
パワーアンプのシャットダウン（SD: Shut Down）信号を GND に接続し、パワーアンプを常に動 作状態とします。JP7 のハンダを取り除く（オープン）と、AquesTalk pico LSI の PLAY 信号（負極 性）がシャットダウン信号となり、パワーアンプの消費電力を減らすことができます。この設定では 音声再生の前後でノイズが発生します。
(5) JP8, JP9
AquesTalk pico LSI の音声出力をボリューム調節後に GPIO25 経由で M5Stack 内蔵アンプ・スピ ーカーに接続することができます。ATP3011 の場合は JP8 を、ATP3012 の場合は JP9 をハンダで短 絡（クローズ）します。Core2 では内蔵スピーカーの構成が異なるため接続できません。
6. サンプルプログラム

以下からダウンロードしてください。
GitHub「PCB-MBUS-AquesTalk-pico-LSI」 https://github.com/botanicfields/PCB-MBUS-AquesTalk-pico-LSI

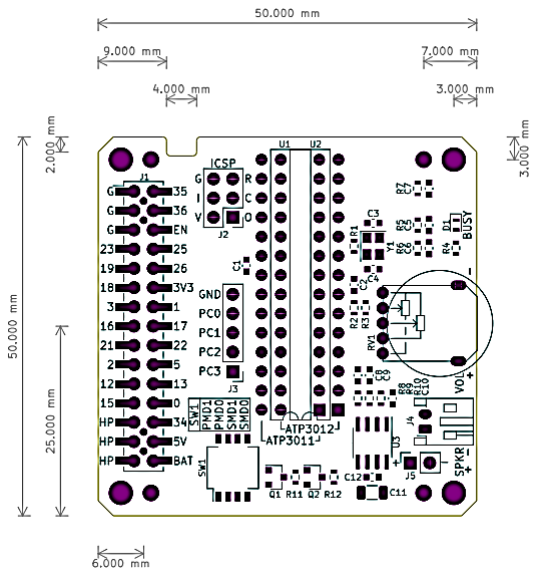
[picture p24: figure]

7. 基板裏面、表面

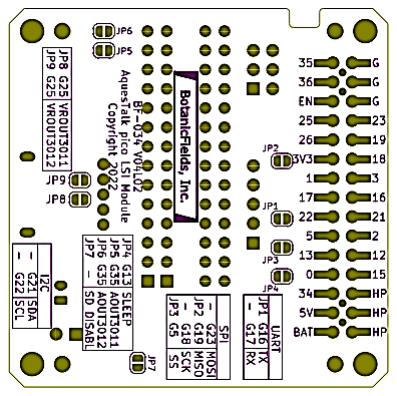
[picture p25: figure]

以上

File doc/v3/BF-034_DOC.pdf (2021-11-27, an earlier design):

BF-034 V03L01

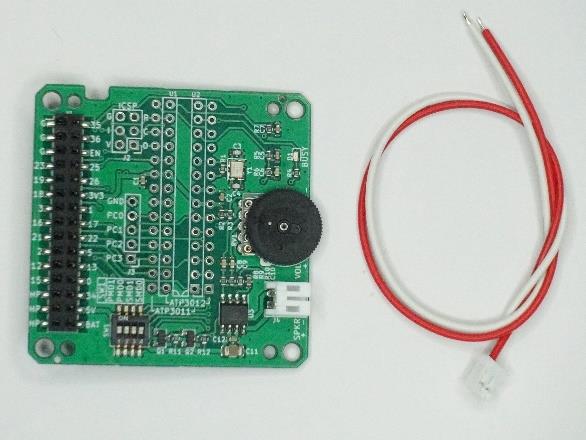
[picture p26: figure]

1 | Copyright 2021 BotanicFields, Inc.

## M5Stack 用 AquesTalk pico LSI モジュール基板

市販の音声合成専用 LSI「AquesTalk pico LSI」（別売）を M-BUS モ ジュールとして M5Stack に取り付けるための半完成基板です。 詳細は、以下を参照ください。
GitHub「PCB-MBUS-AquesTalk-pico-LSI」 https://github.com/botanicfields/PCB-MBUS-AquesTalk-pico-LSI Qiita「AquesTalk pico LSI を M5Stack の I2C, UART, SPI で動かす」 https://qiita.com/BotanicFields/items/fff644f408c291e5a5f0

AquesTalk pico LSI の詳細は、データシートを参照ください。 ATP3011: https://www.a-quest.com/archive/manual/atp3011_datasheet.pdf ATP3012: https://www.a-quest.com/archive/manual/atp3012_datasheet.pdf

1. 特徴
① AquesTalk pico LSI（28 ピン DIP タイプ）1 個を搭載できます。
② ATP3011, ATP3012 の両方に対応しています。
③ パワーアンプ（LM4871）を内蔵し、スピーカーを直接駆動できます。
④ AquestTalk pico LSI を 3.3V で動作させ、M-BUS に直結できます。
⑤ プロトモジュール（別売）のモールドを流用し、M5Stack に取り付けできます。 ⑥ スピーカー以外のケーブル接続が不要です。
⑦ DIP スイッチで動作モード・通信モードを設定できます。
⑧ インタフェースを I2C, UART, SPI から選べます。
⑨ AquesTalk pico LSI の音声出力を M-BUS から取り込めます。 ⑩ M5Stack のリセットで AquesTalk pico LSI をリセットします。 ⑪ スタンドアロンモードのためのランドがあります。
2. 商品内容
① M-BUS モジュール基板（半完成品）1 枚
② スピーカーケーブル 1 組（2 ピン PH 相当コネクタ付き、20cm 片端ストリップ済） ③ 説明書（本書）
3. 別途必要なもの
① AquesTalk pico LSI（秋月電子通商扱い）音声合成ＬＳＩ ＡＴＰ３０１１Ｆ１－ＰＵ（ゆっくりな女性の音声）https://akizukidenshi.com/catalog/g/gI-06220/ＡＴＰ３０１１Ｆ４－ＰＵ（かわいい女性の音声） https://akizukidenshi.com/catalog/g/gI-05665/
ＡＴＰ３０１１Ｍ６－ＰＵ（男性の音声） | https://akizukidenshi.com/catalog/g/gI-06225/
ＡＴＰ３０１２Ｆ６－ＰＵ（女性の音声明瞭版） | https://akizukidenshi.com/catalog/g/gI-09973/
ＡＴＰ３０１２Ｒ５－ＰＵ（小型ロボットの音声） https://akizukidenshi.com/catalog/g/gI-11517/ ② M5Stack 用プロトモジュール（スイッチチサイエンス扱い） https://www.switch-science.com/catalog/3650/

③ スピーカー: 4～8Ω 程度、1W 以上が望ましいです。
④ 工具類: ハンダ、ハンダごて、ニッパー、六角レンチ(0.5mm)、カッター、ピンセットなど ⑤ M5Stack: サンプルプログラムは、M5Stack Core Basic で動作確認しています。
⑥ Arudino-IDE が動作する環境
4. モジュール基板の組み立て
① AquesTalk pico LSI の取り付け
AquestTalk pico LSI（28 ピン DIP パッケージ）を 1 個搭載できます。ATP3011 と ATP3012 とでは 取り付け穴が異なります。基板上のシルク印刷に従ってピンを差し込み、ハンダ付けします。ハンダ付 け後、基板裏面から飛び出しているピンを短く切ってください。IC ソケットは使用できません。プロト モジュールのモールドに収まらなくなります。


② モールドの取り付け
プロトモジュール（別売）のモールドおよびネジ 4
本を流用して、M5Stack の M-BUS モジュールに仕立 てることができます。モールドを基板に取り付ける前
に、ボリュームやスピーカー出力コネクタの部分をモ
ールドから切り取ります。

③ スピーカーの接続
付属のケーブルで J4 とスピーカー（別売）を接続します。GND には接続しないでください。
5. モジュールの設定
① DIP スイッチ
動作モードおよび使用するインタフェース（通信モード）に合わせて、モジュール基板上の DIP スイ ッチを設定します。設定にはピンセットなどが必要です。おすすめは I2C 接続です。出荷時の設定は、 セーフモード、I2C 接続です。

(*1) ATP3011 の場合 SLEEP 解除後の'?'送信で自動設定。ATP3012 の場合 EEPROM に設定

DIP スイッチ

1 | 2 | 3 | 4 | 動作モード | 通信モード | 備考
OFF | OFF | OFF | ON | コマンド入力モード | I2C | I2C アドレスは EEPROM に設定した値 （初期値 0x2E）
OFF | ON | OFF | ON | セーフモード | I2C | I2C アドレスは強制的に 0x2E
OFF | OFF | OFF | OFF | コマンド入力モード | UART | 設定されたスピードで動作 (*1)
OFF | ON | OFF | OFF | セーフモード | UART | 強制的に 9600bps で動作
OFF | - | ON | OFF | - | SPI mode 3 | -
OFF | - | ON | ON | - | SPI mode 0 | サンプルプログラムは SPI mode 0 で動作
ON | OFF | - | - | スタンドアロンモード | - | PC0-3 の信号入力によりプリセットメッ セージを選択して再生
ON | ON | - | - | デモモード | - | プリセットメッセージを順番に自動再生

左: ATP3011 右:ATP3012

② ハンダジャンパ
モジュール基板裏面のジャンパ JP1-JP7 をハンダで短絡（クローズ）することにより、GPIO と AquesTalk pico LSI の信号ピンを接続できます。
(1) JP1, JP2, JP3
使用するインタフェースに合わせて JP1, JP2, JP3 をハンダで短絡（クローズ）します。I2C の場合 は JP1, JP2, JP3 を全てオープンのままで使用できます。他の用途に影響がなければ JP1, JP2, JP3 を 短絡（クローズ）することで全てのインタフェースを使用可能です。
(2) JP4
AquesTalk pico LSI の SLEEP ピンを GPIO13 に接続できます。GPIO13 = Low で AquesTalk pico LSI がスリープ状態になります。ATP3011 の UART 接続において 9600bps より速い速度が必要な場 合、「セーフモード」ではなく「コマンド入力モード」とし、速度設定のために SLEEP を使用します。
(3) JP5, JP6
AquesTalk pico LSI の音声出力を GPIO35 から M5Stack に取り込むことができます。ATP3011 の 場合は JP5 を、ATP3012 の場合は JP6 をハンダで短絡（クローズ）します。
(4) JP7
パワーアンプのシャットダウン（SD: Shut Down）信号を GND に接続し、パワーアンプを常に動 作状態とします。JP7 のハンダを取り除く（オープン）と、AquesTalk pico LSI の PLAY 信号（負極 性）がシャットダウン信号となり、パワーアンプの消費電力を減らすことができます。この設定では 音声再生の前後でノイズが発生します。
6. サンプルプログラム
以下からダウンロードしてください。
GitHub「PCB-MBUS-AquesTalk-pico-LSI」 https://github.com/botanicfields/PCB-MBUS-AquesTalk-pico-LSI
ジャンパ | GPIO | AquesTalk pico LSI | 出荷時設定
JP1 | 16 | UART-TX | オープン
JP2 | 19 | SPI-MISO | オープン
JP3 | 5 | SPI-SS | オープン
JP4 | 13 | SLEEP | オープン
JP5 | 35 | Analog Out of ATP3011 | オープン
JP6 | 35 | Analog Out of ATP3012 | オープン
JP7 | GND | Shut Down of Power Amplifier | クローズ

7. 基板表面、裏面

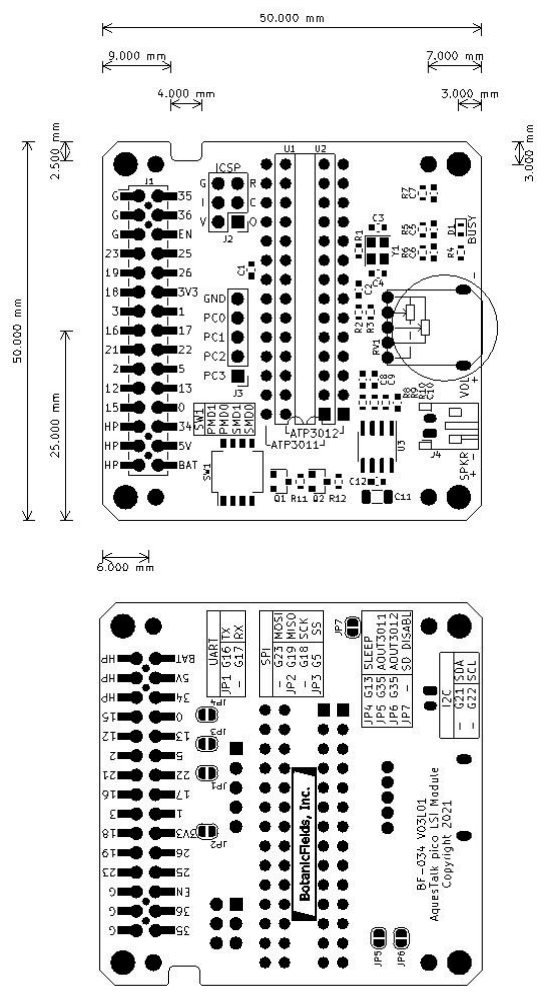
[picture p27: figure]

以上

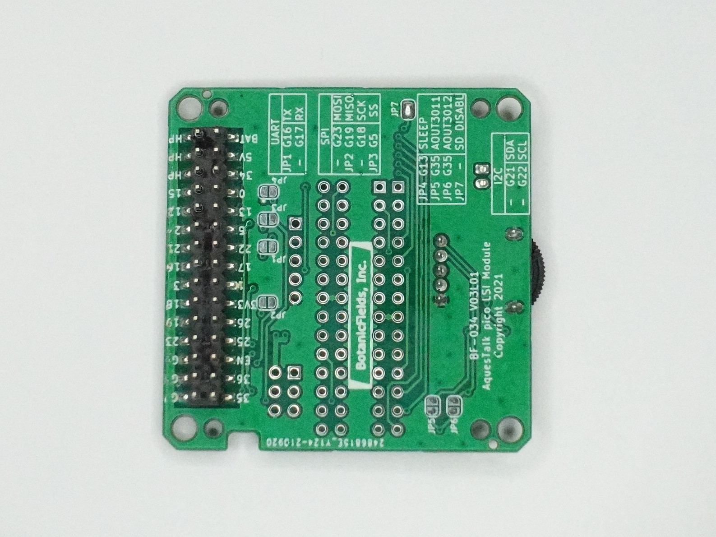
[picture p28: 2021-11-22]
image/product2.JPG

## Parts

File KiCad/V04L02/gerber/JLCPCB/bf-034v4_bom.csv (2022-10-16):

Comment | Designator | Footprint | LCSC
1u | C10 | bf:BF@C_0603_1608Metric | C15849
22u | C11 | Capacitor_SMD:C_1206_3216Metric | C5672
100n | C1,C2,C5,C12 | bf:BF@C_0603_1608Metric | C14663
10p | C3,C4 | bf:BF@C_0603_1608Metric | C1634
22n | C6 | bf:BF@C_0603_1608Metric | C21122
10n | C7 | bf:BF@C_0603_1608Metric | C57112
33n | C8,C9 | bf:BF@C_0603_1608Metric | C21117
BUSY | D1 | bf:BF@LED_0603_1608Metric | C72038
MountingHole | H1,H2,H3,H4 | bf:BF@MountingHole_3.2mm_M3
MountingHole | H5,H6,H7,H8 | bf:BF@MountingHole_2.2mm_M2
M-BUS | J1 | bf:BF@M5Stack_MBUS
ICSP | J2 | Connector_PinHeader_2.54mm:PinHeader_2x03_P2.54mm_Vertical
PRESET | J3 | Connector_PinHeader_2.54mm:PinHeader_1x05_P2.54mm_Vertical
SPKR | J4 | Connector_JST:JST_PH_S2B-PH-K_1x02_P2.00mm_Horizontal
SPKR | J5 | Connector_PinSocket_2.54mm:PinSocket_1x02_P2.54mm_Vertical
TXD | JP1 | Jumper:SolderJumper-2_P1.3mm_Open_RoundedPad1.0x1.5mm
MISO | JP2 | Jumper:SolderJumper-2_P1.3mm_Open_RoundedPad1.0x1.5mm
SS | JP3 | Jumper:SolderJumper-2_P1.3mm_Open_RoundedPad1.0x1.5mm
SLEEP | JP4 | Jumper:SolderJumper-2_P1.3mm_Open_RoundedPad1.0x1.5mm
AOUT3011 | JP5 | Jumper:SolderJumper-2_P1.3mm_Open_RoundedPad1.0x1.5mm
AOUT3012 | JP6 | Jumper:SolderJumper-2_P1.3mm_Open_RoundedPad1.0x1.5mm
SD_DISABLE | JP7 | Jumper:SolderJumper-2_P1.3mm_Open_RoundedPad1.0x1.5mm
VROUT3011 | JP8 | Jumper:SolderJumper-2_P1.3mm_Open_RoundedPad1.0x1.5mm
VROUT3012 | JP9 | Jumper:SolderJumper-2_P1.3mm_Open_RoundedPad1.0x1.5mm
DTC143Z | Q1,Q2 | Package_TO_SOT_SMD:SOT-23 | C15236
1M | R1 | bf:BF@R_0603_1608Metric | C22935
68k | R10 | bf:BF@R_0603_1608Metric | C23231
10k | R2,R3,R11,R12 | bf:BF@R_0603_1608Metric | C25804
2.2k | R4,R6 | bf:BF@R_0603_1608Metric | C4190
470 | R5 | bf:BF@R_0603_1608Metric | C23179
3.3k | R7 | bf:BF@R_0603_1608Metric | C22978
22k | R8,R9 | bf:BF@R_0603_1608Metric | C31850
10kA | RV1 | bf:BF@RK10J
MODE | SW1 | Button_Switch_SMD:SW_DIP_SPSTx04_Slide_KingTek_DSHP04TS_W7.62mm_P1.27mm | C319050
ATP3011 | U1 | Package_DIP:DIP-28_W7.62mm
ATP3012 | U2 | Package_DIP:DIP-28_W7.62mm
LM4871 | U3 | Package_SO:SOIC-8_3.9x4.9mm_P1.27mm | C7554
16MHz | Y1 | Crystal:Crystal_SMD_3225-4Pin_3.2x2.5mm | C13738

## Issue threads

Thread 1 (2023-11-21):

[Question][M5Stack Core2 IoT] UARTモード でのGPIOアドレスについて

nagayaoh, 2023-11-21:
## 概要: UARTモード でのGPIOアドレスについて
### Issueタイプ [Question]
### 問い合わせ内容
- ボード動作：　動作中
- ドキュメント内容と実際が異なる
  - ドキュメントではGPIOの割り当ては以下の記載
　　　  - rx: 16
　　　  - tx: 17
  - 環境でSerial2の割り当て(ソースコード)を追ってみると、
　　　  - rx: 13
　　　  - tx: 14
- コメント
  - 動作しているので、パッケージの差異あるいはドキュメント外の仕様かとも思いましたが、念の為確認です。
  - 何か懸念があればフィードバックください

### 環境情報
- Board Ver. : v4
- Pico LSI: ATP3012
- 開発環境: PlatformIO (Core 6.1.11·Home 3.4.4)
　　　- Board: M５Stack Core2
　　　- 確認Package: M5Core2
- ボード ジャンパ設定
　　　- JP1: Close UART-TX
　　　- JP2: Close SPI-MISO
　　　- JP3: Close SPI-SS
　　　- JP4: Close SLEEP ※ 3012だが誤ってCloseしたまま → **何か影響ありますか？**
　　　- JP6: Close Analog Out of ATP3012

## 確認した情報
#### Serial2 定義
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

#### logical pins
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

#### map logical pins to GPIO numbers
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

#### 【引用】 Readme.md ジャンパピン
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

uehara00, 2023-11-21:
ご指摘ありがとうございます。
当初M5Stack Core1で動作確認し、後日Core2用のサンプルプログラムを追加しましたが、ドキュメントの更新に漏れがありました。ドキュメントを更新いたします。販売中の商品への反映はもうしばらくかかります。

Core1のM-BUSピン配置
https://docs.m5stack.com/en/core/basic_v2.7
Core2のM-BUSピン配置
https://docs.m5stack.com/en/core/core2

uehara00, 2023-11-21:
シリアルインターフェースのボーレート設定において、ATP3012ではSLEEPは使用しませんが、ATP3012にもSLEEP機能があり本来のSLEEP動作をさせることができます。サンプルプログラムの範囲では特に影響はないと思います。
JP4をOpenにすると、GPIO19(Core1の場合はGPIO13)を他の用途に使える様になります。

ATP3012データシート
https://www.a-quest.com/archive/manual/atp3012_datasheet.pdf

uehara00, 2023-11-21:
README.mdとdoc/v4/BF-034v4l2_DOC.pdfを更新しました。

nagayaoh, 2023-11-21:
フィードバックありがとうございます。

確認いたしましたので、本件Closeいたします。

Closed 2023-11-21.

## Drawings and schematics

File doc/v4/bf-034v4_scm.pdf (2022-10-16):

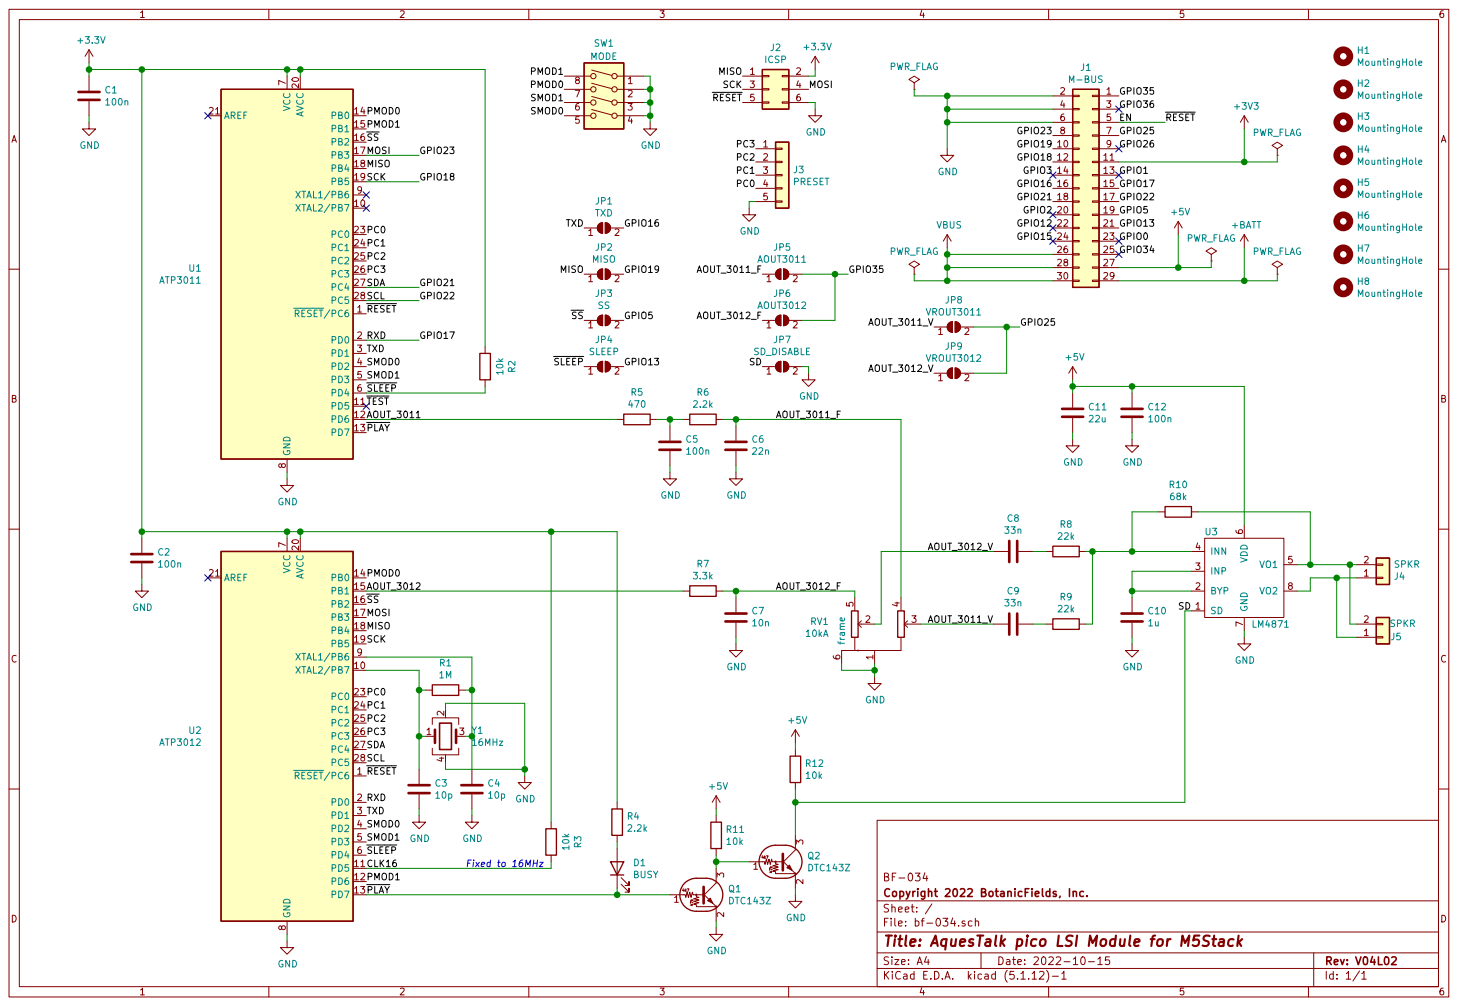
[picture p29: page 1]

File: bf-034.sch Sheet: / Copyright 2022 BotanicFields, Inc. BF-034 C3

Id: 1/1 Title: AquesTalk pico LSI Module for M5Stack

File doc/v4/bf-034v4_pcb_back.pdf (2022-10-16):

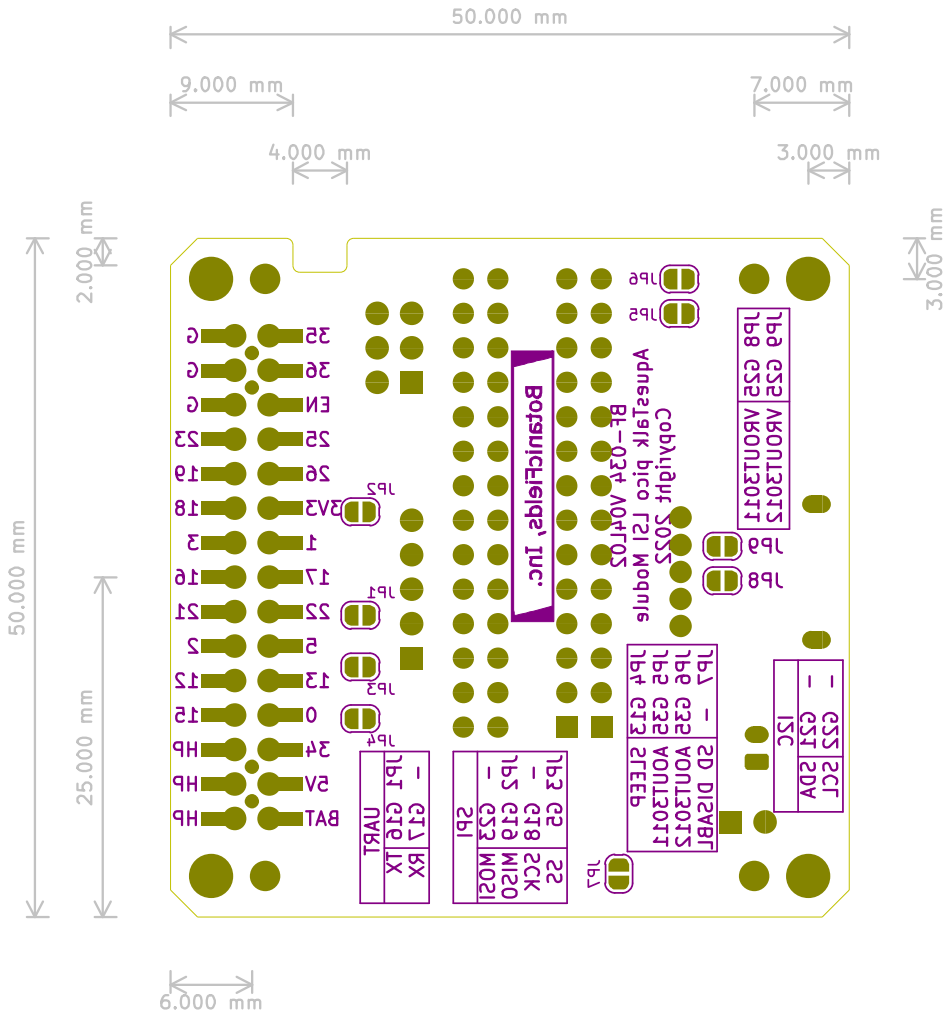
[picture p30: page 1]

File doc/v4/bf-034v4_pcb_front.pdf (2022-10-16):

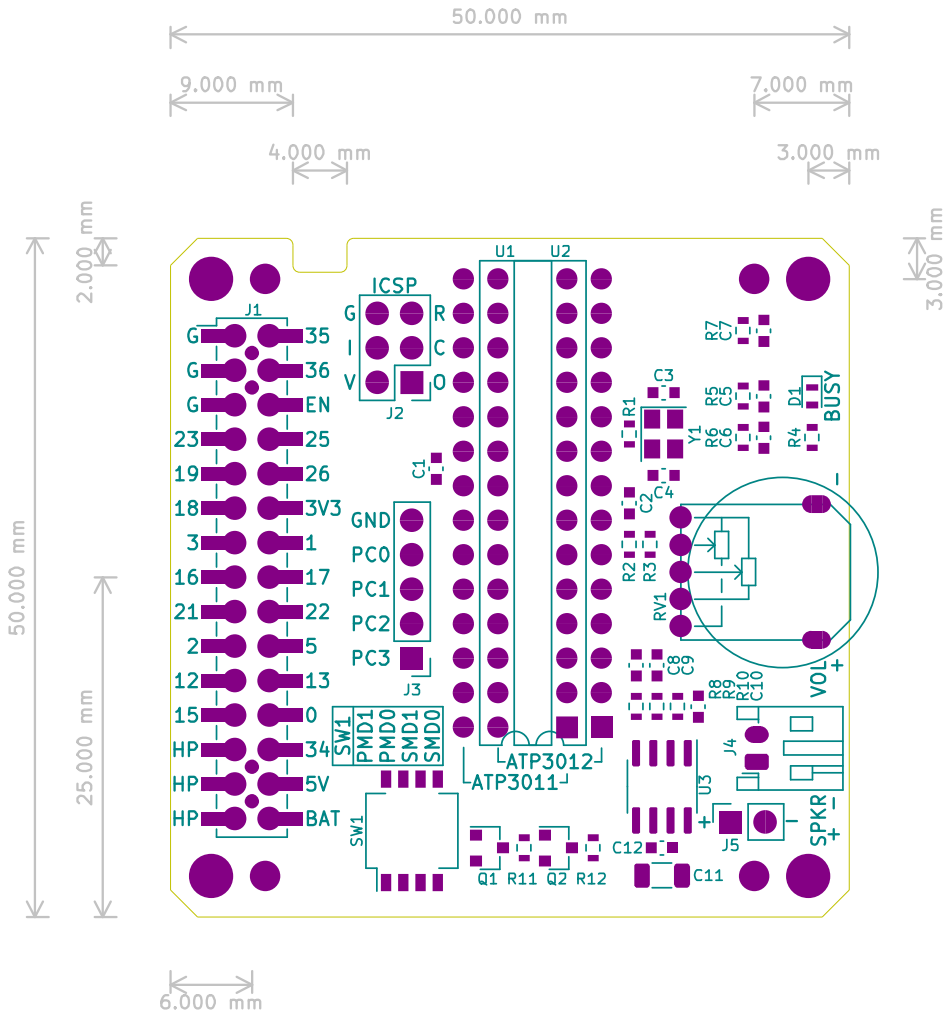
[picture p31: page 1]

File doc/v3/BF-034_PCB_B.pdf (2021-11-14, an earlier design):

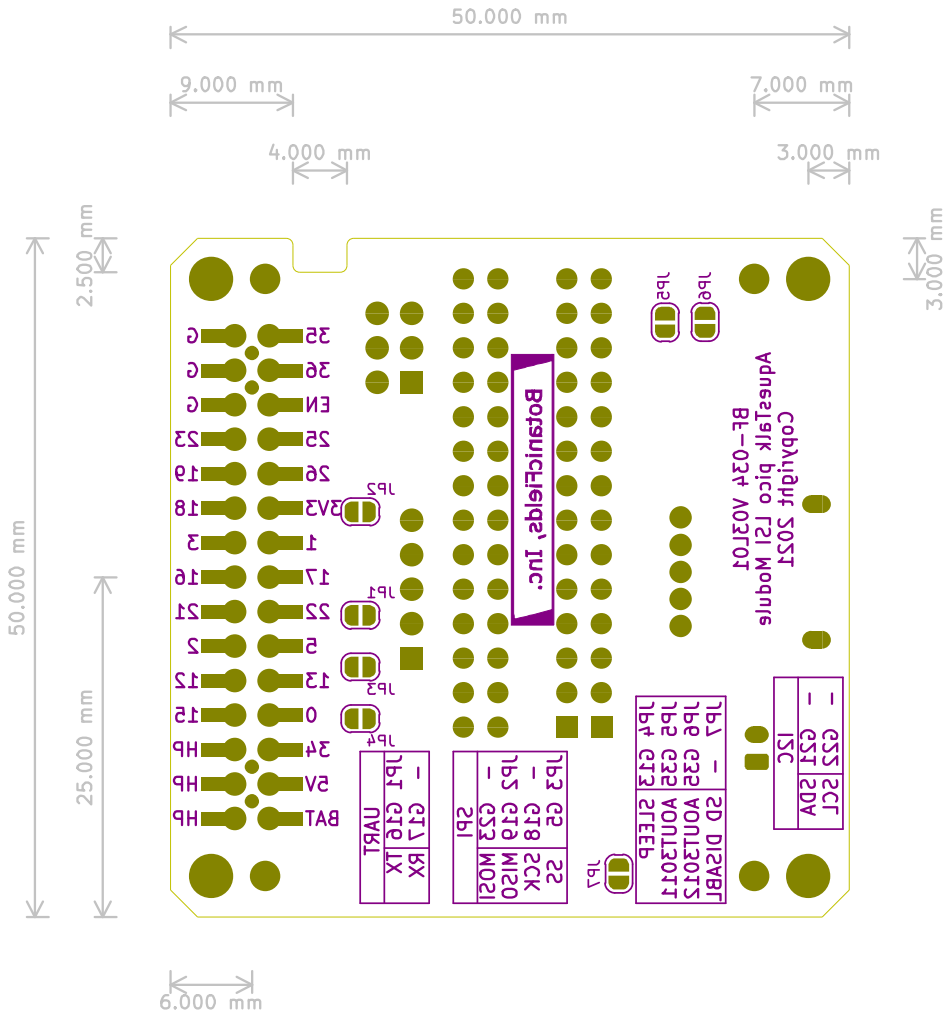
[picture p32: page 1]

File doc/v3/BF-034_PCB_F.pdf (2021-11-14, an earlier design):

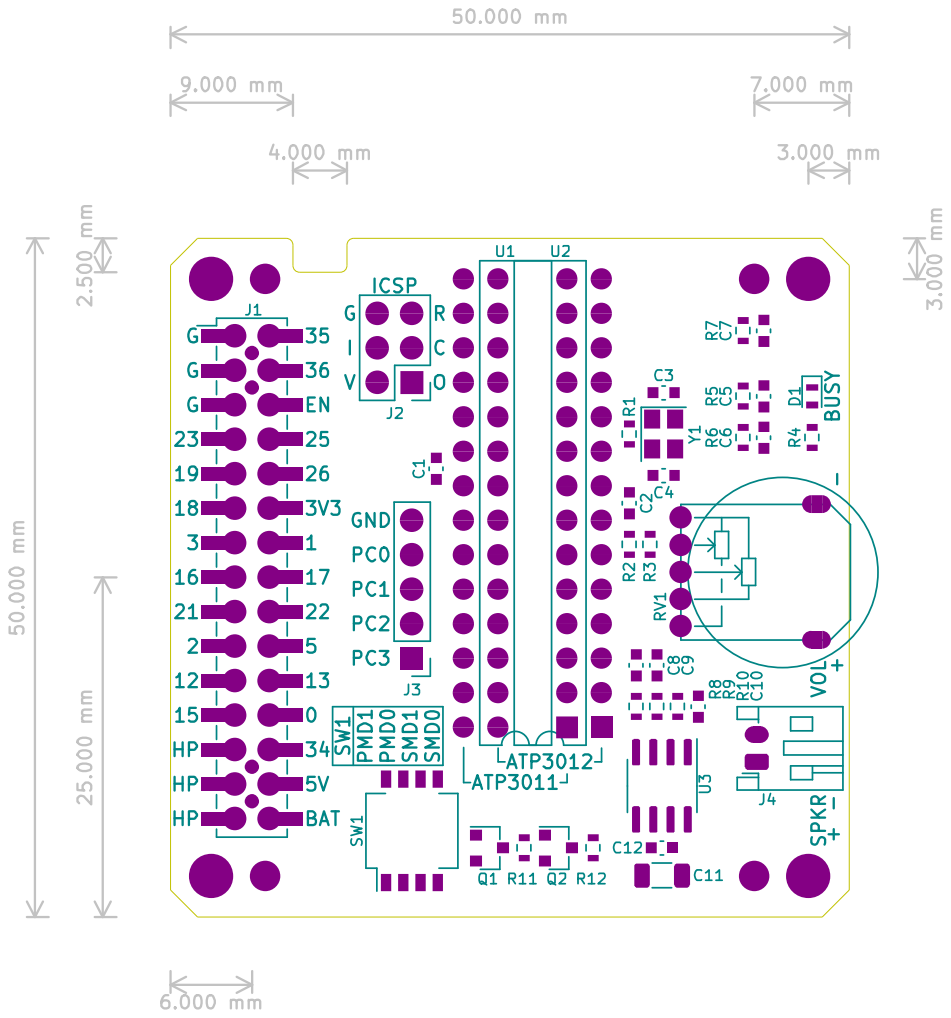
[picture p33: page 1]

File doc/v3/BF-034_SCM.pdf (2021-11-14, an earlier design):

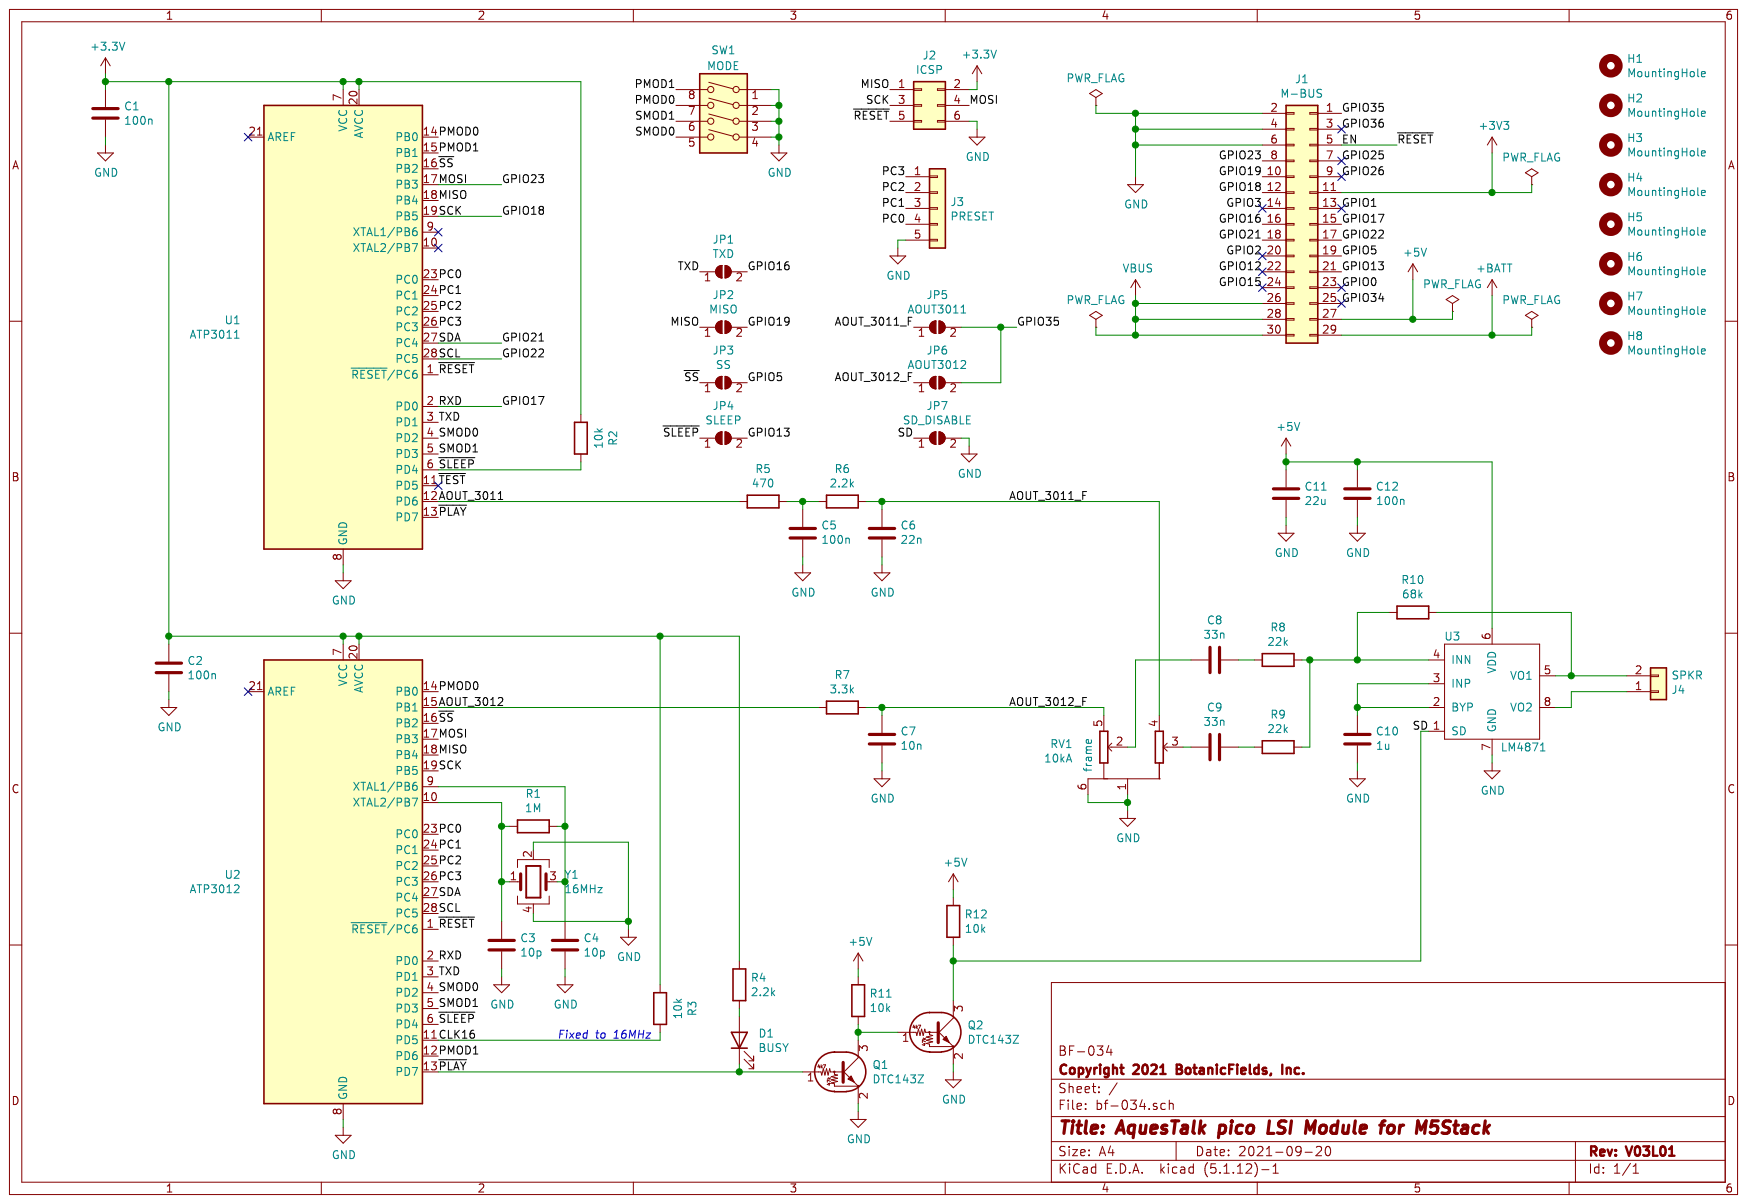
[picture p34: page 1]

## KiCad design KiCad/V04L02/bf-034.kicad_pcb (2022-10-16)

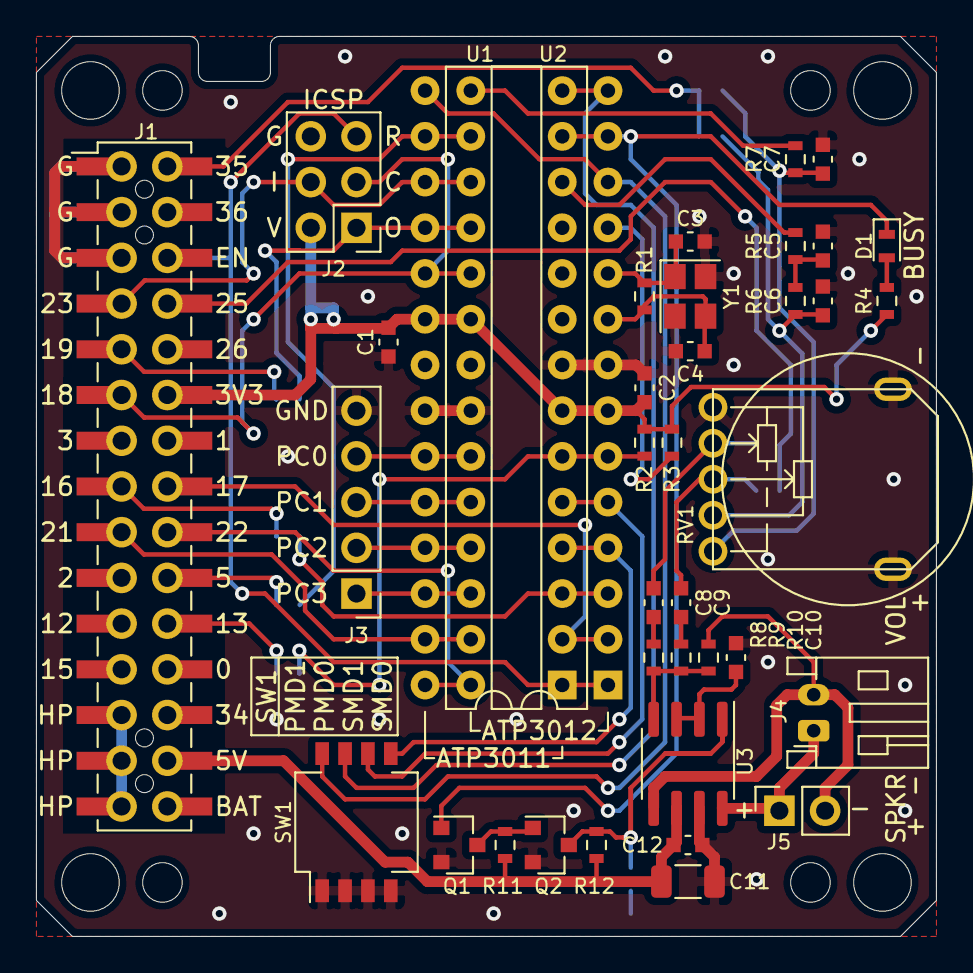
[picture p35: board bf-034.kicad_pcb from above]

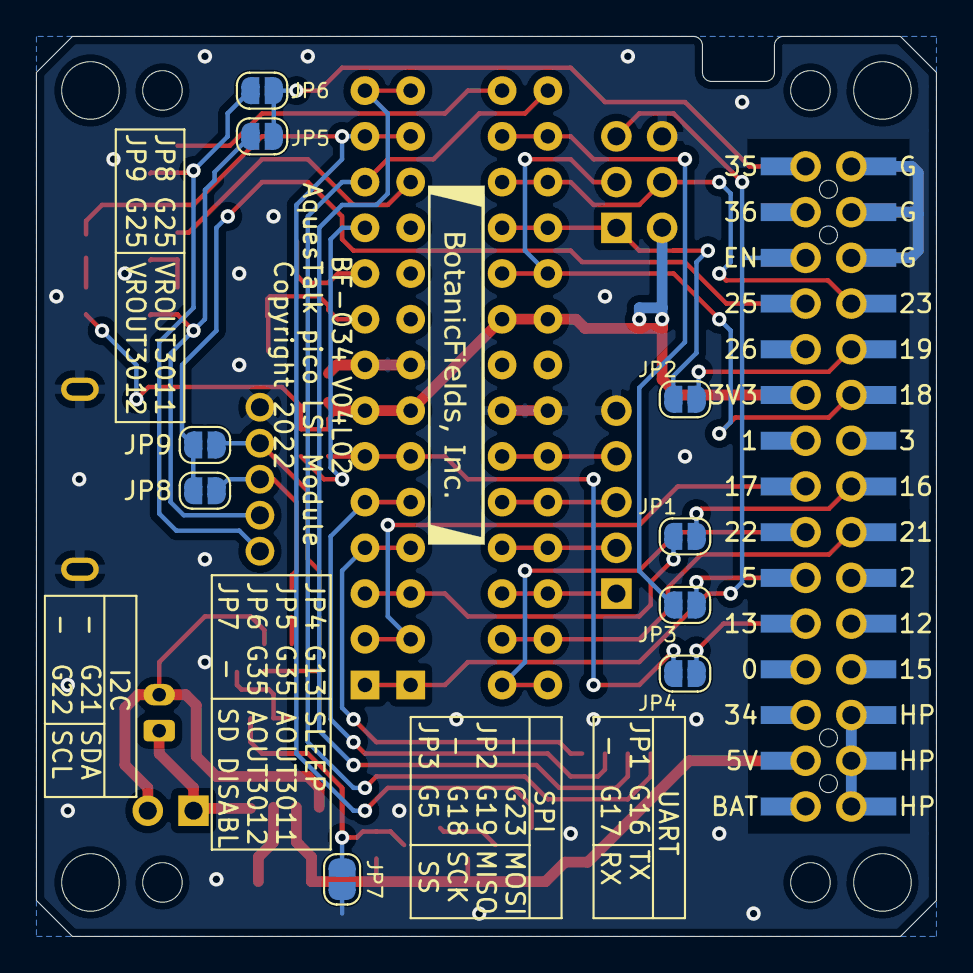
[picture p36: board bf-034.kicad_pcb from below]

Board: 2 copper layers, 50.0 x 50.0 mm, 55 parts (9 on the bottom side), 48 nets.

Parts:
C1, C2, C5, C12: 100n; BF@C_0603_1608Metric
C3, C4: 10p; BF@C_0603_1608Metric
C6: 22n; BF@C_0603_1608Metric
C7: 10n; BF@C_0603_1608Metric
C8, C9: 33n; BF@C_0603_1608Metric
C10: 1u; BF@C_0603_1608Metric
C11: 22u; C_1206_3216Metric
D1: BUSY; BF@LED_0603_1608Metric
H1, H2, H3, H4: MountingHole; BF@MountingHole_3.2mm_M3
H5, H6, H7, H8: MountingHole; BF@MountingHole_2.2mm_M2
J1: M-BUS; BF@M5Stack_MBUS
J2: ICSP; PinHeader_2x03_P2.54mm_Vertical
J3: PRESET; PinHeader_1x05_P2.54mm_Vertical
J4: SPKR; JST_PH_S2B-PH-K_1x02_P2.00mm_Horizontal
J5: SPKR; PinSocket_1x02_P2.54mm_Vertical
JP1: TXD; SolderJumper-2_P1.3mm_Open_RoundedPad1.0x1.5mm
JP2: MISO; SolderJumper-2_P1.3mm_Open_RoundedPad1.0x1.5mm
JP3: SS; SolderJumper-2_P1.3mm_Open_RoundedPad1.0x1.5mm
JP4: SLEEP; SolderJumper-2_P1.3mm_Open_RoundedPad1.0x1.5mm
JP5: AOUT3011; SolderJumper-2_P1.3mm_Open_RoundedPad1.0x1.5mm
JP6: AOUT3012; SolderJumper-2_P1.3mm_Open_RoundedPad1.0x1.5mm
JP7: SD_DISABLE; SolderJumper-2_P1.3mm_Open_RoundedPad1.0x1.5mm
JP8: VROUT3011; SolderJumper-2_P1.3mm_Open_RoundedPad1.0x1.5mm
JP9: VROUT3012; SolderJumper-2_P1.3mm_Open_RoundedPad1.0x1.5mm
Q1, Q2: DTC143Z; SOT-23
R1: 1M; BF@R_0603_1608Metric
R2, R3, R11, R12: 10k; BF@R_0603_1608Metric
R4, R6: 2.2k; BF@R_0603_1608Metric
R5: 470; BF@R_0603_1608Metric
R7: 3.3k; BF@R_0603_1608Metric
R8, R9: 22k; BF@R_0603_1608Metric
R10: 68k; BF@R_0603_1608Metric
RV1: 10kA; BF@RK10J
SW1: MODE; SW_DIP_SPSTx04_Slide_KingTek_DSHP04TS_W7.62mm_P1.27mm
U1: ATP3011; DIP-28_W7.62mm
U2: ATP3012; DIP-28_W7.62mm
U3: LM4871; SOIC-8_3.9x4.9mm_P1.27mm
Y1: 16MHz; Crystal_SMD_3225-4Pin_3.2x2.5mm

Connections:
+3V3: C1.1, C2.1, J1.11, J2.2, R2.2, R3.2, R4.1, U1.7, U1.20, U2.7, U2.20
+5V: C11.1, C12.1, J1.27, R11.1, R12.1, U3.6
/AOUT_3011: R5.2, U1.12
/AOUT_3011_F: C6.2, JP5.1, R6.1, RV1.4
/AOUT_3011_V: C9.2, JP8.1, RV1.3
/AOUT_3012: R7.2, U2.15
/AOUT_3012_F: C7.2, JP6.1, R7.1, RV1.5
/AOUT_3012_V: C8.2, JP9.1, RV1.2
/CLK16: R3.1, U2.11
/EN: J1.5, J2.5, U1.1, U2.1
/GPIO5: J1.19, JP3.2
/GPIO13: J1.21, JP4.2
/GPIO16: J1.16, JP1.2
/GPIO17: J1.15, U1.2, U2.2
/GPIO18: J1.12, J2.3, U1.19, U2.19
/GPIO19: J1.10, JP2.2
/GPIO21: J1.18, U1.27, U2.27
/GPIO22: J1.17, U1.28, U2.28
/GPIO23: J1.8, J2.4, U1.17, U2.17
/GPIO25: J1.7, JP8.2, JP9.2
/GPIO35: J1.1, JP5.2, JP6.2
/MISO: J2.1, JP2.1, U1.18, U2.18
/PC0: J3.4, U1.23, U2.23
/PC1: J3.3, U1.24, U2.24
/PC2: J3.2, U1.25, U2.25
/PC3: J3.1, U1.26, U2.26
/PMOD0: SW1.7, U1.14, U2.14
/PMOD1: SW1.8, U1.15, U2.12
/SD: JP7.1, Q2.3, R12.2, U3.1
/SMOD0: SW1.5, U1.4, U2.4
/SMOD1: SW1.6, U1.5, U2.5
/TXD: JP1.1, U1.3, U2.3
/~PLAY: D1.1, Q1.1, U1.13, U2.13
/~SLEEP: JP4.1, R2.1, U1.6, U2.6
/~SS: JP3.1, U1.16, U2.16
GND: C1.2, C2.2, C3.2, C4.2, C5.1, C6.1, C7.1, C10.1, C11.2, C12.2, J1.2, J1.4, J1.6, J2.6, J3.5, JP7.2, Q1.2, Q2.2, RV1.1, RV1.6, SW1.1, SW1.2, SW1.3, SW1.4, U1.8, U1.22, U2.8, U2.22, U3.7, Y1.2, Y1.4
unnamed: C3.1, R1.2, U2.10, Y1.1
unnamed: C4.1, R1.1, U2.9, Y1.3
unnamed: C5.2, R5.1, R6.2
unnamed: C8.1, R8.2
unnamed: C9.1, R9.2
unnamed: C10.2, U3.2, U3.3
unnamed: D1.2, R4.2
unnamed: J4.1, J5.1, U3.8
unnamed: J4.2, J5.2, R10.1, U3.5
unnamed: Q1.3, Q2.1, R11.2
unnamed: R8.1, R9.1, R10.2, U3.4
VBUS: J1.26, J1.28, J1.30

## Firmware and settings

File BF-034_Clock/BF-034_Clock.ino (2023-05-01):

// Copyright 2021 BotanicFields, Inc.
// BF-031 PCF8563 RTC Module for M-BUS
// BF-034 AquesTalk pico LSI for M-BUS
// example
#include <M5Stack.h>
#include <Free_Fonts.h>
#include <WiFi.h>
#include <WiFiManager.h>
#include "BF_Pcf8563.h"
#include "BF_RtcxNtp.h"
#include "BF_ResetReason.h"
#include "BF_AquesTalkPicoWire.h"

//..:....1....:....2....:....3....:....4....:....5....:....6....:....7..
// for NTP
const char* time_zone  = "JST-9";
const char* ntp_server = "pool.ntp.org";
bool localtime_valid(false);
struct tm local_tm;

//..:....1....:....2....:....3....:....4....:....5....:....6....:....7..
// for LCD
const int max_chars(26);
char str[max_chars];
TFT_eSprite spr = TFT_eSprite(&M5.Lcd);

// put text into a sprite, push the sprite to LCD
void SprStr(TFT_eSprite *spr, const char *str, const GFXfont *font, int fore_color, int back_color, int pos_x, int pos_y, int width)
{
  spr->setFreeFont(font);
  spr->setTextSize(1);
  spr->createSprite(width, spr->fontHeight());
  spr->fillSprite(back_color);
  spr->setTextColor(fore_color, back_color);
  spr->setTextDatum(MC_DATUM);  // Middle-Center
  spr->drawString(str, width / 2, spr->fontHeight() / 2, GFXFF);
  spr->pushSprite(pos_x, pos_y);
  spr->deleteSprite();
}

//..:....1....:....2....:....3....:....4....:....5....:....6....:....7..
// for WiFi
const int wifi_config_portal_timeout_sec(60);
const unsigned int wifi_retry_interval_ms(60000);
      unsigned int wifi_retry_last_ms(0);
const int wifi_retry_max_times(3);
      int wifi_retry_times(0);

wl_status_t wifi_status(WL_NO_SHIELD);

const char* wl_status_str[] = {
  "WL_IDLE_STATUS",      // 0
  "WL_NO_SSID_AVAIL",    // 1
  "WL_SCAN_COMPLETED",   // 2
  "WL_CONNECTED",        // 3
  "WL_CONNECT_FAILED",   // 4
  "WL_CONNECTION_LOST",  // 5
  "WL_DISCONNECTED",     // 6
  "WL_NO_SHIELD",        // 7 <-- 255
  "wl_status invalid",   // 8
};

const char* WlStatus(wl_status_t wl_status)
{
  if (wl_status >= 0 && wl_status <= 6) {
    return wl_status_str[wl_status];
  }
  if (wl_status == 255) {
    return wl_status_str[7];
  }
  return wl_status_str[8];
}

void WifiCheck()
{
  wl_status_t wifi_status_new = WiFi.status();
  if (wifi_status != wifi_status_new) {
    wifi_status = wifi_status_new;
    Serial.printf("[WiFi]%s\n", WlStatus(wifi_status));
  }

  // retry interval
  if (millis() - wifi_retry_last_ms < wifi_retry_interval_ms) {
    return;
  }
  wifi_retry_last_ms = millis();

  // reboot if wifi connection fails
  if (wifi_status == WL_CONNECT_FAILED) {
    Serial.print("[WiFi]connect failed: rebooting..\n");
    ESP.restart();
    return;
  }

  // let the wifi process do if wifi is not disconnected
  if (wifi_status != WL_DISCONNECTED) {
    wifi_retry_times = 0;
    return;
  }

  // reboot if wifi is disconnected for a long time
  if (++wifi_retry_times > wifi_retry_max_times) {
    Serial.print("[WiFi]disconnect timeout: rebooting..\n");
    ESP.restart();
    return;
  }

  // reconnect, and reboot if reconnection fails
  Serial.printf("[WiFi]reconnect %d\n", wifi_retry_times);
  if (!WiFi.reconnect()) {
    Serial.print("[WiFi]reconnect failed: rebooting..\n");
    ESP.restart();
    return;
  };
}

void WifiConfigModeCallback(WiFiManager *wm)
{
  M5.Lcd.setTextColor(TFT_YELLOW, TFT_BLACK);
  M5.Lcd.println("WiFi config portal:");
  M5.Lcd.println(wm->getConfigPortalSSID().c_str());
  M5.Lcd.println(WiFi.softAPIP().toString().c_str());
}

//..:....1....:....2....:....3....:....4....:....5....:....6....:....7..
// to test RTCx
const bool enable_clock_out(true);
const bool enable_int(true);
const int  timer_10s(10);
const int  timer_60s(60);
const bool enable_interrupt(true);
const bool pulse_mode(true);  // generate short pulse
const bool keep_flag(true);   // every 60sec
bool clock_out_interrupt_enable(false);

// to monitor RTCx pins
const int pin_rtcx_clock_out(36);
const int pin_rtcx_interrupt35(35);
const int pin_rtcx_interrupt13(13);
bool rtcx_exist(false);
bool rtcx_interrupt35(false);
bool rtcx_interrupt13(false);
bool lcd_clock_out(false);
bool lcd_interrupt35(false);
bool lcd_interrupt13(false);
unsigned int lcd_interrupt35_ms(0);
unsigned int lcd_interrupt13_ms(0);

void RtcxInterrupt35()
{
  rtcx_interrupt35 = true;
}

void RtcxInterrupt13()
{
  rtcx_interrupt13 = true;
}

//..:....1....:....2....:....3....:....4....:....5....:....6....:....7..
// for TTS(Text To Speech)
AquesTalkPicoWire aqtp;
const int tts_max(64);
char tts[tts_max];
bool aqtp_exist(false);

//..:....1....:....2....:....3....:....4....:....5....:....6....:....7..
// for loop control
const unsigned int loop_period_ms(100);  // 100ms
      unsigned int loop_last_ms;

void setup()
{
  const bool lcd_enable(true);
  const bool sd_enable(true);
  const bool serial_enable(true);
  const bool i2c_enable(true);
  M5.begin(lcd_enable, sd_enable, serial_enable, i2c_enable);

  M5.Lcd.wakeup();
  M5.Lcd.setBrightness(100);
  M5.Lcd.fillScreen(TFT_BLACK);
  M5.Lcd.setTextSize(2);
  M5.Lcd.setTextDatum(TL_DATUM);

  // to check reset by INT-pin of RTCx PCF8563
  RESET_REASON reset_reason_0 = rtc_get_reset_reason(0);
  M5.Lcd.setTextColor(TFT_WHITE, TFT_BLACK);   M5.Lcd.print("CPU0:");
  M5.Lcd.setTextColor(TFT_YELLOW, TFT_BLACK);  M5.Lcd.println(ResetReason(reset_reason_0));
  Serial.printf("Reset Reason CPU0: %d=", reset_reason_0);
  Serial.println(ResetReasonVerbose(reset_reason_0));
  RESET_REASON reset_reason_1 = rtc_get_reset_reason(1);
  M5.Lcd.setTextColor(TFT_WHITE, TFT_BLACK);   M5.Lcd.print("CPU1:");
  M5.Lcd.setTextColor(TFT_YELLOW, TFT_BLACK);  M5.Lcd.println(ResetReason(reset_reason_1));
  Serial.printf("Reset Reason CPU1: %d=", reset_reason_1);
  Serial.println(ResetReasonVerbose(reset_reason_1));

  // RTCx PCF8563: connect and start
  M5.Lcd.setTextColor(TFT_WHITE, TFT_BLACK);  M5.Lcd.print("I2C, RTCx:");
  if (rtcx.Begin(Wire) == 0) {
    rtcx_exist = true;
    M5.Lcd.setTextColor(TFT_GREEN, TFT_BLACK);  M5.Lcd.println("OK");
    if (SetTimeFromRtcx(time_zone)) {
      localtime_valid = true;
      M5.Lcd.setTextColor(TFT_WHITE, TFT_BLACK);  M5.Lcd.println("RTCx valid");
    }
  }
  else {
    M5.Lcd.setTextColor(TFT_RED, TFT_BLACK);  M5.Lcd.println("NG");
  }
  if (!localtime_valid) {
    Serial.print("RTC not valid: set the localtime temporarily\n");
    local_tm.tm_year = 117;  // 2017 > 2016, getLocalTime() returns true
    local_tm.tm_mon  = 0;    // January
    local_tm.tm_mday = 1;
    local_tm.tm_hour = 0;
    local_tm.tm_min  = 0;
    local_tm.tm_sec  = 0;
    struct timeval tv = { mktime(&local_tm), 0 };
    settimeofday(&tv, NULL);
  }
  getLocalTime(&local_tm);
  Serial.print(&local_tm, "localtime: %A, %B %d %Y %H:%M:%S\n");
  // print sample: must be < 64
  //....:....1....:....2....:....3....:....4....:....5....:....6....
  //localtime: Wednesday, September 11 2021 11:10:46

  // RTCx PCF8563: for adjusting trimmer capacitor
  M5.Lcd.setTextColor(TFT_WHITE, TFT_BLACK);  M5.Lcd.print("Clock Out:");
  if (rtcx.ClockOutForTrimmer(enable_clock_out) == 0) {
    M5.Lcd.setTextColor(TFT_GREEN, TFT_BLACK);  M5.Lcd.println("OK");
  }
  else {
    M5.Lcd.setTextColor(TFT_RED, TFT_BLACK);  M5.Lcd.println("NG");
  }

  // RTCx PCF8563: timer
  M5.Lcd.setTextColor(TFT_WHITE, TFT_BLACK);  M5.Lcd.print("Set timer:");
  double timer_return = rtcx.SetTimer(timer_10s);
  M5.Lcd.setTextColor(TFT_YELLOW, TFT_BLACK);  M5.Lcd.print(timer_return);
  if (timer_return != 0.0) {
    M5.Lcd.setTextColor(TFT_GREEN, TFT_BLACK);  M5.Lcd.println("OK");
  }
  else {
    M5.Lcd.setTextColor(TFT_RED, TFT_BLACK);  M5.Lcd.println("NG");
  }

  // RTCx PCF8563: timer interrupt
  M5.Lcd.setTextColor(TFT_WHITE, TFT_BLACK);  M5.Lcd.print("Enable Interrupt:");
  if (rtcx.EnableTimerInterrupt(enable_interrupt, pulse_mode, keep_flag) == 0) {
    M5.Lcd.setTextColor(TFT_GREEN, TFT_BLACK);  M5.Lcd.println("OK");
  }
  else {
    M5.Lcd.setTextColor(TFT_RED, TFT_BLACK);  M5.Lcd.println("NG");
  }

  // WiFi start
  M5.Lcd.setTextColor(TFT_WHITE, TFT_BLACK);  M5.Lcd.println("WiFi connecting.. ");
  WiFiManager wm;  // blocking mode only

  // erase SSID/Key to force rewrite
  if (digitalRead(BUTTON_A_PIN) == LOW) {
    wm.resetSettings();
    M5.Lcd.setTextColor(TFT_YELLOW, TFT_BLACK);  M5.Lcd.println("SSID/Key erased");
    delay(3000);
  }

  // WiFi connect
  wm.setConfigPortalTimeout(wifi_config_portal_timeout_sec);
  wm.setAPCallback(WifiConfigModeCallback);
  if (wm.autoConnect()) {
    M5.Lcd.setTextColor(TFT_GREEN, TFT_BLACK);  M5.Lcd.println("OK");
  }
  else {
    M5.Lcd.setTextColor(TFT_RED, TFT_BLACK);  M5.Lcd.println("NG");
  }
  WiFi.setSleep(false);  // https://macsbug.wordpress.com/2021/05/02/buttona-on-m5stack-does-not-work-properly/
  wifi_retry_last_ms = millis() - wifi_retry_interval_ms;

  // NTP start
  NtpBegin(time_zone, ntp_server);
  M5.Lcd.setTextColor(TFT_WHITE, TFT_BLACK);  M5.Lcd.println("NTP start");
  delay(3000);

  // wait button-C to proceed into loop
  M5.Lcd.setTextColor(TFT_CYAN, TFT_BLACK);  M5.Lcd.println("Button-C to continue:");
  while (!M5.BtnC.wasReleased()) {
    M5.update();
    if (RtcxUpdate()) {
      localtime_valid = true;  // SNTP sync completed
    }
  }

  // RTCx PCF8563: disable CLKO and INT
  rtcx.ClockOutForTrimmer(!enable_clock_out);
  rtcx.DisableTimer();
  rtcx.DisableTimerInterrupt();
  clock_out_interrupt_enable = false;

  // for RTCx monitor
  if (rtcx_exist) {
    pinMode(pin_rtcx_clock_out, INPUT);
    pinMode(pin_rtcx_interrupt13, INPUT);
    attachInterrupt(pin_rtcx_interrupt13, RtcxInterrupt13, FALLING);
//    pinMode(pin_rtcx_interrupt35, INPUT);
//    attachInterrupt(pin_rtcx_interrupt35, RtcxInterrupt35, FALLING);
  }

  // LCD control
  M5.Lcd.fillScreen(TFT_BLACK);
  M5.Lcd.setFreeFont(FSS9);  // FreeSans9pt7b, height=22px
  M5.Lcd.setTextSize(1);
  M5.Lcd.setTextColor(TFT_BLACK, TFT_OLIVE);
  M5.Lcd.setTextDatum(TC_DATUM);  // Align Middle-Center
  M5.Lcd.setTextPadding(M5.Lcd.width());
  M5.Lcd.drawString("BotanicFields, Inc.", M5.Lcd.width() / 2, 0, GFXFF);
  M5.Lcd.setTextDatum(BC_DATUM);  // Align Bottom-Center
  M5.Lcd.setTextPadding(M5.Lcd.width() / 6);
  M5.Lcd.drawString("CLKO", M5.Lcd.width() * 21 / 100, M5.Lcd.height(), GFXFF);
  M5.Lcd.drawString("Date", M5.Lcd.width() * 50 / 100, M5.Lcd.height(), GFXFF);
  M5.Lcd.drawString("Time", M5.Lcd.width() * 79 / 100, M5.Lcd.height(), GFXFF);

  // start TTS
  aqtp.Begin(Wire);
  int return_code = aqtp.Send("$");
  Serial.printf("AquesTalk pico LSI return code = %d\n", return_code);
  if (return_code == 0) {
    aqtp_exist = true;
    aqtp.ShowRes();
    aqtp.WriteSpeed();  // set default
    aqtp.WritePause();  // set default
  }

  // loop control
  loop_last_ms = millis();
}

void loop()
{
  // WiFi recovery
  WifiCheck();

  // NTP sync
  if (RtcxUpdate()) {
    localtime_valid = true;  // SNTP sync completed
  }
  getLocalTime(&local_tm);

  // table clock
  int forecolor = TFT_WHITE;
  if (!localtime_valid) {
    forecolor = TFT_DARKGREY;
  }
  strftime(str, max_chars, "%H:%M:%S",  &local_tm);  SprStr(&spr, str, FSS24, forecolor, TFT_BLACK, 0,  30, 320);  // FreeSans24pt7b, height=56px
  strftime(str, max_chars, "%A",        &local_tm);  SprStr(&spr, str, FSS12, forecolor, TFT_BLACK, 0,  90, 320);  // FreeSans12pt7b, height=29px
  strftime(str, max_chars, "%B %d, %Y", &local_tm);  SprStr(&spr, str, FSS12, forecolor, TFT_BLACK, 0, 120, 320);  // FreeSans12pt7b, height=29px

  forecolor = TFT_RED;
  if (wifi_status == WL_CONNECTED) {
    forecolor = TFT_BLACK;
  }
  SprStr(&spr, WlStatus(wifi_status),             FSS9, forecolor,     TFT_BLACK, 60, 151, 260);  // FreeSans9pt7b, height=22px

  SprStr(&spr, WiFi.SSID().c_str(),               FSS9, TFT_LIGHTGREY, TFT_BLACK, 60, 173, 260);  // FreeSans9pt7b, height=22px
  SprStr(&spr, WiFi.localIP().toString().c_str(), FSS9, TFT_LIGHTGREY, TFT_BLACK, 60, 195, 260);  // FreeSans9pt7b, height=22px

  // monitor RTCx
  if (rtcx_exist) {
    lcd_clock_out = false;
    if (digitalRead(pin_rtcx_clock_out) == LOW) {
      lcd_clock_out = true;
    }
    if (rtcx_interrupt13) {
      rtcx_interrupt13 = false;
      lcd_interrupt13 = true;
      lcd_interrupt13_ms = millis();
    }
    if (rtcx_interrupt35) {
      rtcx_interrupt35 = false;
      lcd_interrupt35 = true;
      lcd_interrupt35_ms = millis();
    }
    forecolor = TFT_BLACK;
    if (lcd_clock_out) {
      forecolor = TFT_YELLOW;
    }
    SprStr(&spr, "CLKO", FSS9, forecolor, TFT_BLACK, 0, 195, 60);  // FreeSans9pt7b, height=22px

    forecolor = TFT_BLACK;
    if (lcd_interrupt13) {
      forecolor = TFT_YELLOW;
      if (millis() - lcd_interrupt13_ms > 1000) {
        lcd_interrupt13 = false;
      }
    }
    SprStr(&spr, "INT13", FSS9, forecolor, TFT_BLACK, 0, 151, 60);  // FreeSans9pt7b, height=22px

    forecolor = TFT_BLACK;
    if (lcd_interrupt35) {
      forecolor = TFT_YELLOW;
      if (millis() - lcd_interrupt35_ms > 1000) {
        lcd_interrupt35 = false;
      }
    }
    SprStr(&spr, "INT35", FSS9, forecolor, TFT_BLACK, 0, 173, 60);  // FreeSans9pt7b, height=22px
  }

  M5.update();
  // toggle monitoring RTCx
  if (M5.BtnA.wasReleased()) {
    if (rtcx_exist) {
      if (clock_out_interrupt_enable) {
        clock_out_interrupt_enable = false;
        rtcx.ClockOutForTrimmer(!enable_clock_out);
        rtcx.DisableTimer();
        rtcx.DisableTimerInterrupt();
      }
      else {
        clock_out_interrupt_enable = true;
        rtcx.ClockOutForTrimmer(enable_clock_out);
        rtcx.SetTimer(timer_60s);
        rtcx.EnableTimerInterrupt(enable_interrupt, pulse_mode, keep_flag);
      }
    }
  }
  // speech date
  if (M5.BtnB.wasReleased()) {
    if (localtime_valid && aqtp_exist) {
      strftime(tts, tts_max, "<NUMK VAL=%Y COUNTER=nenn>,",  &local_tm);  aqtp.Send(tts);
      strftime(tts, tts_max, "<NUMK VAL=%m COUNTER=gatu>,",  &local_tm);  aqtp.Send(tts);
      strftime(tts, tts_max, "<NUMK VAL=%d COUNTER=nichi>,", &local_tm);  aqtp.Send(tts);
      switch (local_tm.tm_wday) {
        case  0: strcpy(tts, "nichi/yo'ubide_su\r"); break;
        case  1: strcpy(tts, "getsu/yo'ubide_su\r"); break;
        case  2: strcpy(tts, "ka/yo'ubide_su\r"   ); break;
        case  3: strcpy(tts, "sui/yo'ubide_su\r"  ); break;
        case  4: strcpy(tts, "moku/yo'ubide_su\r" ); break;
        case  5: strcpy(tts, "kin/yo'ubide_su\r"  ); break;
        case  6: strcpy(tts, "do/yo'ubide_su\r"   ); break;
        default: strcpy(tts, "de_su\r"            ); break;
      }
      aqtp.Send(tts);
    }
  }
  // speech time
  if (M5.BtnC.wasReleased()) {
    if (localtime_valid && aqtp_exist) {
      strftime(tts, tts_max, "<NUMK VAL=%H COUNTER=ji>,<NUMK VAL=%M COUNTER=funn>de_su\r", &local_tm);  aqtp.Send(tts);
                            //....:....1....:....2....:....3....:....4....:....5....:....6...
    }
  }
  if (aqtp_exist) {
    aqtp.ShowRes(2);
  }

  // loop control
  unsigned int delay_ms(0);
  unsigned int elapse_ms = millis() - loop_last_ms;
  if (elapse_ms < loop_period_ms) {
    delay_ms = loop_period_ms - elapse_ms;
  }
  delay(delay_ms);
  loop_last_ms = millis();
//  Serial.printf("loop elapse = %dms\n", elapse_ms);  // monitor elapsed time
}

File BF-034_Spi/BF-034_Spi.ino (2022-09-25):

// Copyright 2021 BotanicFields, Inc.
// BF-034 AquesTalk pico LSI Module for M5Stack
// example

#include <M5Stack.h>
#include <Free_Fonts.h>
#include "BF_AquesTalkPicoSpi.h"
#include "BF_M5AdcWave.h"

AquesTalkPicoSpi aqtp;
SPIClass vspi(VSPI);
const int vspi_ss = 5;

const char* preset_msg[] = {
// message must be less than 127 characters
// ....:....1....:....2....:....3....:....4....:....5....:....6....:....7....:....8....:....9....:....A....:....8....:....C....:..
  "re'-jide_su.yo'-koso wata'ku_sitati,sho'kka-e\r",
  "iti'jide_su.ittai,do'-natte/iru'node_suka zo'rutaisa\r",
  "ni'jide_su.ma'da,deki'nainde_suka sinigamiha'kase\r",
  "sa'njide_su.sho'kka-no,se'kai,seifuku/ke'ikakuwa cha_ku'cha_kuto,_susun'deima_su\r",
  "yo'jide_su.omedeto-/goza'i/ma'_su jikken'wa,dai'seiko-de_su\r",
  "go'jide_su.sho'kka-no/tikara'wa,muge'n/na'node_su\r",
  "roku'jide_su.urotae'/nai'de,kudasa'i,jigo'kutai_si\r",
  "siti'jide_su.wata'_ku_sitati,sho'kka-no/shuku'teki kamen'raida-o/tao'_sunode_su\r",
  "hati'jide_su.sa'-/yukina'sai sho'kka-no/mono'tatiyo\r",
  "ku'jide_su.kiki'masho- ana'tano,niho'n,seifuku/ke'ikakuo\r",
  "jyu'-jide_su.oda'marinasai,jigo'kutai_si su'beteno/sippa'iwa,ana'tano/se'ide_su\r",
  "jyu-iti'jide_su.sho'kka-wa,su'beteo/haka'i_si,se'kaio/_si'hai_sima_su\r",
  "jyu-ni'jide_su.kaizo-/ni'ngenga,se'kaio/ugo'ka_si sono/kaizo-/ni'ngen+o,_si'hai/suru'noga,wata'ku_side_su\r",
  "ohayo-/gozaima'_su.ta'datini,saga_si/da'_sunode_su\r",
  "oyasumi/nasa'i.se'kaiwa,sho'kka-no/mono'de_su\r",
};

//..:....1....:....2....:....3....:....4....:....5....:....6....:....7..
// main
enum play_command_t {
  play_stop,
  play_current,
  play_next,
  play_previous,
  play_continuous,  // play continuously from current
  play_forward,     // play continuously from next
  play_backward,    // play continuously from previous
};
play_command_t play_command(play_stop);
int msg_selected(0);
const unsigned int msg_space(500);
const unsigned int loop_period_ms(100);
      unsigned int loop_last_ms;

void setup()
{
  const bool lcd_enable(true);
  const bool sd_enable(true);
  const bool serial_enable(true);
  const bool i2c_enable(true);
  M5.begin(lcd_enable, sd_enable, serial_enable, i2c_enable);

  // defined by Arduino-ESP32
  //  const int vspi_sclk(18);  // SCLK = GPIO18 as default
  //  const int vspi_miso(19);  // MISO = GPIO19 as default
  //  const int vspi_mosi(23);  // MOSI = GPIO23 as default
  //  const int vspi_ss(5);     // SS   = GPIO5  as default
  //  vspi->begin(vspi_sclk, vspi_miso, vspi_mosi, vspi_ss);
  vspi.begin();
  aqtp.Begin(vspi, vspi_ss);

  // "true" if sleep pin is connected
  if (true /*false*/) {
    const int aqtp_sleep_pin(13);  // GPIO13 for sleep pin of M-BUS module
    pinMode(aqtp_sleep_pin, OUTPUT);
    digitalWrite(aqtp_sleep_pin, HIGH);
  }

  // "true" to write preset message into EEPROM
  if (/*true*/ false)
    aqtp.WritePresetMsg(preset_msg, sizeof(preset_msg)/sizeof(preset_msg[0]));

  // "true" to dump EEPROM to the serial monitor
  if (/*true*/ false)
    aqtp.DumpEeprom();

  aqtp.Send("#V\r");  // read version
  for (int i = 0; i < 10; ++i) {
    aqtp.ShowRes();
    delay(200);
  }
  aqtp.Send("#J\r");  // chime sound J
  for (int i = 0; i < 10; ++i) {
    aqtp.ShowRes();
    delay(200);
  }
  aqtp.Send("#K\r");  // chime sound K
  for (int i = 0; i < 10; ++i) {
    aqtp.ShowRes();
    delay(200);
  }

  // set default
  aqtp.WriteSpeed();
  aqtp.WritePause();

  // play control
  play_command = play_stop;
  msg_selected = 0;

  // LCD control
  M5.Lcd.fillScreen(TFT_BLACK);
  M5.Lcd.setFreeFont(FSS9);  // FreeSans9pt7b, height=22px
  M5.Lcd.setTextSize(1);
  M5.Lcd.setTextColor(TFT_BLACK, TFT_OLIVE);
  M5.Lcd.setTextDatum(TC_DATUM);  // Align Middle-Center
  M5.Lcd.setTextPadding(M5.Lcd.width());
  M5.Lcd.drawString("BotanicFields, Inc.", M5.Lcd.width() / 2, 0, GFXFF);
  M5.Lcd.setTextDatum(BC_DATUM);  // Align Bottom-Center
  M5.Lcd.setTextPadding(M5.Lcd.width() / 6);
  M5.Lcd.drawString("Prev", M5.Lcd.width() * 21 / 100, M5.Lcd.height(), GFXFF);
  M5.Lcd.drawString("Play", M5.Lcd.width() * 50 / 100, M5.Lcd.height(), GFXFF);
  M5.Lcd.drawString("Next", M5.Lcd.width() * 79 / 100, M5.Lcd.height(), GFXFF);
  AdcWaveInit();

  // loop control
  loop_last_ms = millis();
}

void loop()
{
  // buttons
  M5.update();
  if (M5.BtnA.wasReleased()) {
    if (aqtp.Busy()) {
      aqtp.Send("$");  // Abort
    }
    play_command = play_previous;
  }
  if (M5.BtnB.wasReleased()) {
    if (aqtp.Busy()) {
      aqtp.Send("$");  // Abort
      play_command = play_stop;
    }
    else {
      play_command = play_current;
    }
  }
  if (M5.BtnC.wasReleased()) {
    if (aqtp.Busy()) {
      aqtp.Send("$");  // Abort
    }
    play_command = play_forward;
  }

  // play messages
  int num_of_msg = sizeof(preset_msg)/sizeof(preset_msg[0]);
  switch (play_command) {
    case play_current:
      if (!aqtp.Busy()) {
        aqtp.Send(preset_msg[msg_selected]);
        play_command = play_stop;
      }
      break;
    case play_next:
      if (!aqtp.Busy()) {
        if (++msg_selected >= num_of_msg)
          msg_selected = 0;
        aqtp.Send(preset_msg[msg_selected]);
        play_command = play_stop;
      }
      break;
    case play_previous:
      if (!aqtp.Busy()) {
        if (--msg_selected < 0)
          msg_selected = num_of_msg - 1;
        aqtp.Send(preset_msg[msg_selected]);
        play_command = play_stop;
      }
      break;
    case play_continuous:
      if (!aqtp.Busy()) {
        delay(msg_space);
        aqtp.Send(preset_msg[msg_selected]);
        if (++msg_selected >= num_of_msg)
          msg_selected = 0;
      }
      break;
    case play_forward:
      if (!aqtp.Busy()) {
        if (++msg_selected >= num_of_msg)
          msg_selected = 0;
        delay(msg_space);
        aqtp.Send(preset_msg[msg_selected]);
      }
      break;
    case play_backward:
      if (!aqtp.Busy()) {
        if (--msg_selected < 0)
          msg_selected = num_of_msg - 1;
        delay(msg_space);
        aqtp.Send(preset_msg[msg_selected]);
      }
      break;
    default:
        play_command = play_stop;
      break;
  }
  aqtp.ShowRes(2);
  AdcWave();

  // loop control
  unsigned int delay_ms(0);
  unsigned int elapse_ms = millis() - loop_last_ms;
  if (elapse_ms < loop_period_ms) {
    delay_ms = loop_period_ms - elapse_ms;
  }
  delay(delay_ms);
  loop_last_ms = millis();
//  Serial.printf("loop elapse = %dms\n", elapse_ms);  // for monitoring elapsed time
}

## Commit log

2021-11-14 PCB
    add PCB data
    [BF-034_PART.csv, bf-034_bom.csv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]
2021-11-21 ADC wave
    add ADC wave demo
2021-11-22 image
    update image
    [bf-034.kicad_pcb, bf-034.sch]
2021-11-22 DOC updated
    [BF-034_PART.csv]
2021-11-23 example
    refine
    [bf-034_bom.csv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]
2021-12-18 examples
    add unsigned related to millis()
2022-10-16 PCB V04
    add PCB V04
    [bf-034.kicad_pcb, bf-034.sch, bf-034v4_bom.csv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]
2022-11-01 Update README.md
    frame of proto module
2023-05-01 BF-034_Clock.ino
    Removed: Wi-Fi check at waiting button-C
